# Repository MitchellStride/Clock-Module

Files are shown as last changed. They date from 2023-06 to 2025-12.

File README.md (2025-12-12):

# 🐦 Hummingbird RP2040 Clock Module ⏰

[]() 
[]() 

[]() 
[]() 

The **Hummingbird RP2040 Clock Module** is designed for crafting artisan clocks by pairing it with different clock faces. Its modular design allows this project to be shared across various display technologies.

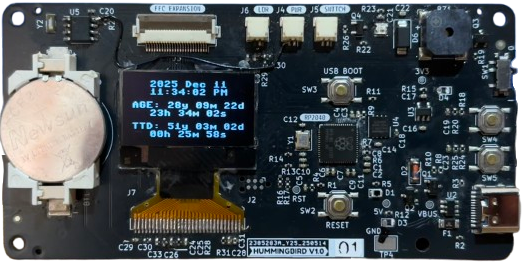
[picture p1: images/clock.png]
Clock Display


The test OLED above shows time, my age, and my time to death countdown based on my life expectancy.

---

## 🔧 Features
- Raspberry Pi RP2040 microcontroller with dual-core ARM Cortex-M0+
- Highly compatible with JLCPCB's basic SMT components and 2L stackup for cost
- Powered via USB-C with ESD and reverse polarity protection
- DS1307Z+ RTC with CR2032 coin cell backup
- Single-sided design for a compact, flush mount
- Photocell/LDR support for automatic display dimming
- Additional features: piezoelectric buzzer, RGB LED, power switch, and optional OLED
- FFC expansion for modular clock face integration

---

## 📦 Status
> The PCBA has arrived, and is working, it needed one bodge. FW is done.

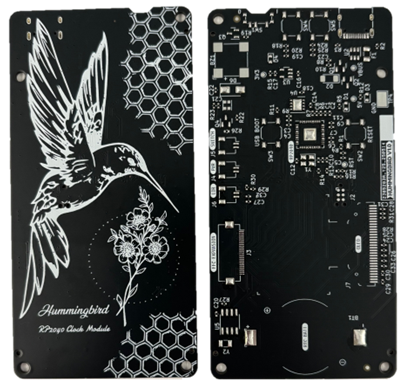
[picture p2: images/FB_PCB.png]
Front and back PCB


---

## 💡 Clock Ideas
Clocks I plan to build using this module:

<details>
<summary>Click to expand</summary>

- **Life Clock:** A countdown to estimated time of death using seven-segment displays
- **Nixie Clock:** A personal take on the classic Nixie tube clock, featuring IN-12 tubes
- **0402 Year Calendar** Inspired by the Yetch THE EVERY DAY GOAL CALENDAR

</details>

---

## 📝 Notes

<details>
<summary>Click to expand</summary>

- I had a few issues with the v1 hardware design since I completed it in roughly two days. Might do a v2.
- From 2024 (schematic design) to 2025 (layout), JLC PCB assembly changed many basic components and increased extended reel fees from $1 → $3, significantly affecting small-run costs.
- The cost per assembled PCB is approximately $8–10 USD, excluding setup fees. A total order of 2 PCBAs + 3 PCBs came to ~$57 + ~$17 shipping. After discounts, the total spent was ~$70 USD, plus $10–20 for extra parts from LCSC or Digikey. The largest expense was reel fees ($30).

See: -> ./images/cost2.png

</details>

---

## 🖼️ Image Appendix

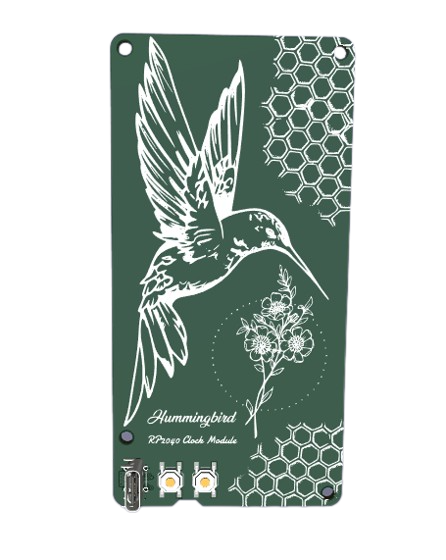
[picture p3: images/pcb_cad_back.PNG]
PCB Back


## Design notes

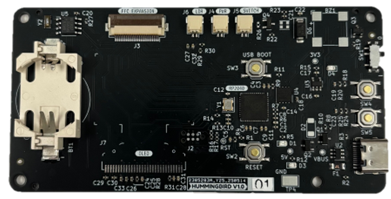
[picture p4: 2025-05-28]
images/F_PCBA1.png

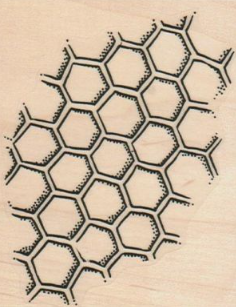
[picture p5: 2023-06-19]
images/assets/comb.PNG

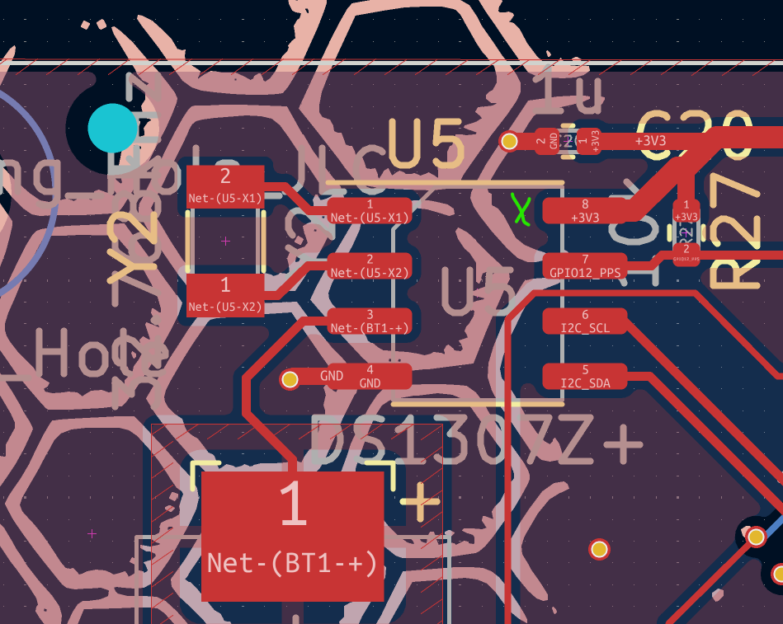
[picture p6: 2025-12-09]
images/ICs/rtc.png

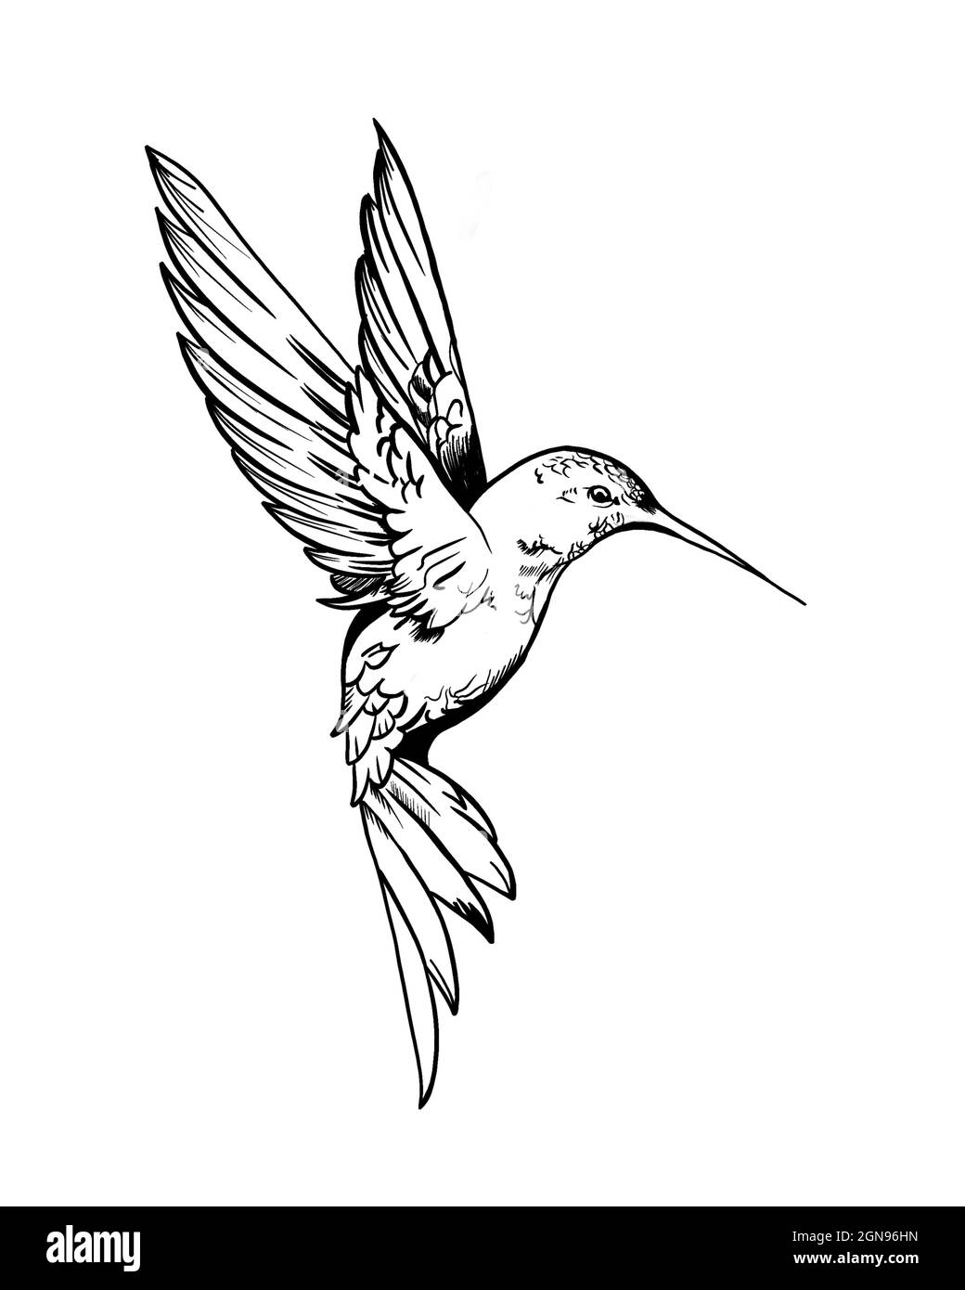
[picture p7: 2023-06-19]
images/assets/bird.jpg

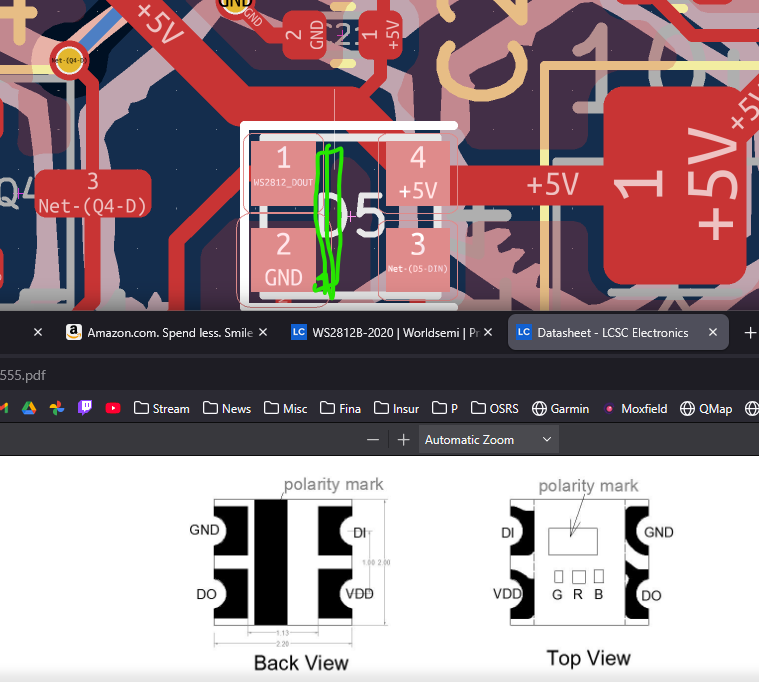
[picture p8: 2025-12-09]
images/ICs/rgb.png

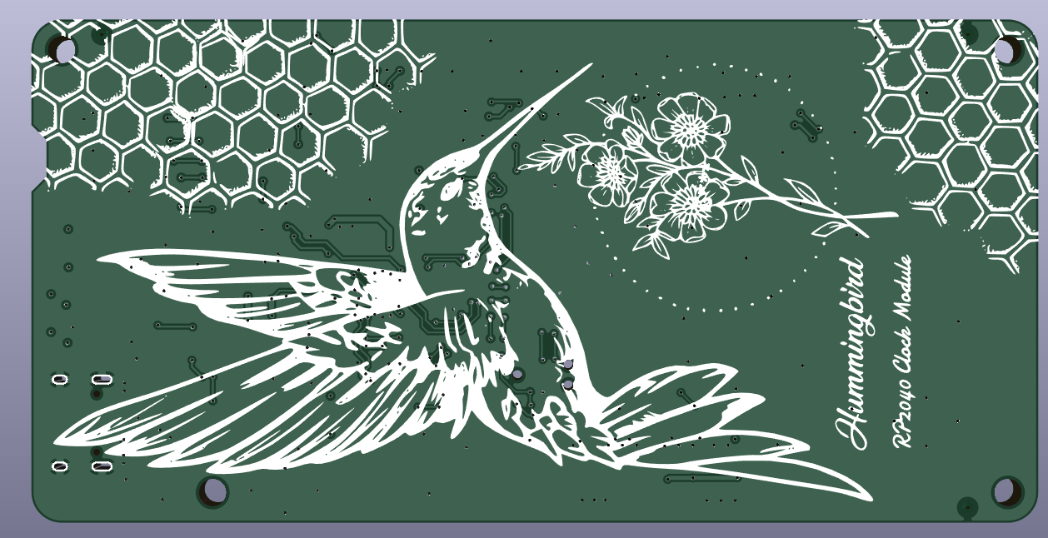
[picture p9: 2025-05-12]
images/20251205_bot3d.png

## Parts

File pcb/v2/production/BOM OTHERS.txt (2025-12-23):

Extras to Order not on PCB BOM:
- C5248005 FFC and assorted, reverse too
- C125626 GL5516 LDR
- OLED 
Wisevision N096-2864KSWEG01-H30
LCSC PN: C2890596
Controller  	SSD1306
- CR2032 Battery

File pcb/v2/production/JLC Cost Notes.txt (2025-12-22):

JLC Cost Notes

Cost https://jlcpcb.com/help/article/pcb-assembly-price
PCBA Type	Economic PCBA	Standard PCBA
Setup fee	$8		$25/Single-side
				$50/Double-side
Stencil also 	1.50 		vs 8
Feeders Fee	$3/ Extended	$1.5 basic/Extended

Economic Limits
Single sided placement (SMT/Thru-hole) 2,4,6-layers
Minimum Package 0402
Minimum IC Pin Spacing 0.4mm vs 0.35mm
Minimum BGA Spacing 0.5mm(center to center) vs 0.35mm(center to center)

SolderMask Colors https://jlcpcb.com/capabilities/pcb-assembly-capabilities
2L, All
4L, Green

2L, Any color, Single Side
4L, Green Single Sided, is a great value choice

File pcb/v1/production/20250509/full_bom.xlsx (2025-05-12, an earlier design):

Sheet: export
# | Reference | Qty | Value | Footprint | DNP | LCSC PN | digi
1 | BT1 | 1 | CR2032 | stride_footprints:Q&J_CR2032-BS-6-1 |  | C70377
2 | BZ1 | 1 | CMT-8504-100-SMT-TR | Buzzer_Beeper:MagneticBuzzer_CUI_CMT-8504-100-SMT |  |  | 102-CMT-8504-100-SMT-CT-ND
3 | C1, C22 | 2 | 10u | Capacitor_SMD:C_0402_1005Metric |  | C15525
4 | C2, C8, C18, C20, C21, C24, C26, C27, C29, C30, C33 | 11 | 1u | Capacitor_SMD:C_0402_1005Metric |  | C52923
5 | C3, C4, C5, C6, C7, C9, C10, C11, C14, C15, C19, C23, C25, C32 | 14 | 0.1u | Capacitor_SMD:C_0402_1005Metric |  | C1525
6 | C12, C13 | 2 | 10p | Capacitor_SMD:C_0402_1005Metric |  | C32949
7 | C16, C17, C31 | 3 | 4.7u | Capacitor_SMD:C_0402_1005Metric |  | C23733
8 | C28 | 1 | 2.2u | Capacitor_SMD:C_0402_1005Metric |  | C12530
9 | D1 | 1 | LED_Y | LED_SMD:LED_0603_1608Metric |  | C72038
10 | D2 | 1 | 5.6V | Diode_SMD:D_MiniMELF |  | C8062
11 | D3 | 1 | LED_B | LED_SMD:LED_0603_1608Metric |  | C72041
12 | D4 | 1 | LED_G | LED_SMD:LED_0603_1608Metric |  | C72043
13 | D5 | 1 | WS2812B-2020 | stride_footprints:WS2812B-2020 |  | C965555
14 | D6 | 1 | SS14 | Diode_SMD:D_SMA |  | C2480
15 | F1 | 1 | 12V 3A | Fuse:Fuse_1206_3216Metric |  | C516068
16 | J1 | 1 | USB_C_Receptacle_USB2.0 | ftp:USB-C-16p |  | C167321
17 | J3 | 1 | FFC 24 | Connector_FFC-FPC:Hirose_FH12-24S-0.5SH_1x24-1MP_P0.50mm_Horizontal |  | C202112
18 | J4, J5, J6 | 3 | 5V | Connector_JST:JST_SH_SM02B-SRSS-TB_1x02-1MP_P1.00mm_Horizontal |  | C160402
19 | J7 | 1 | OLED | stride_footprints:OLED-128O064D_edit_reverse_v2 |  | C2890596
20 | Q1, Q2 | 2 | AO3401A | Package_TO_SOT_SMD:SOT-23 |  | C15127
21 | Q3 | 1 | AO3400A | Package_TO_SOT_SMD:SOT-23 |  | C20917
22 | Q4 | 1 | 2N7002 | Package_TO_SOT_SMD:SOT-23 |  | C8545
23 | R1, R11, R18, R19, R24, R30 | 6 | 1k | Resistor_SMD:R_0402_1005Metric |  | C11702
24 | R2, R3 | 2 | 5.1k | Resistor_SMD:R_0402_1005Metric |  | C25905
25 | R4, R9, R20, R23, R25, R27, R28, R29 | 8 | 10k | Resistor_SMD:R_0402_1005Metric |  | C25744
26 | R5, R12 | 2 | 2.2k | Resistor_SMD:R_0402_1005Metric |  | C25879
27 | R6, R7 | 2 | 22 | Resistor_SMD:R_0402_1005Metric |  | C25092
28 | R8, R10 | 2 | 100k | Resistor_SMD:R_0402_1005Metric |  | C25741
29 | R13, R14 | 2 | 4.7k | Resistor_SMD:R_0402_1005Metric |  | C25900
30 | R15 | 1 | 300 | Resistor_SMD:R_0402_1005Metric |  | C25102
31 | R16, R17 | 2 | 0 | stride_footprints:R_0402_1005Metric_3pad |  | C17168
32 | R22 | 1 | 51 | Resistor_SMD:R_0402_1005Metric |  | C25125
33 | R26 | 1 | 10k | Resistor_SMD:R_0402_1005Metric | DNP | C25744
34 | R31 | 1 | 330k | Resistor_SMD:R_0402_1005Metric |  | C25778
35 | SW1 | 1 | SSSS811101 | stride_footprints:SSSS811101 |  | C109335
36 | SW2, SW3, SW4, SW5 | 4 | TS-1187A-B-A-B | stride_footprints:SW_SPST_TL3342_RT |  | C318884
37 | U1 | 1 | RP2040 | stride_footprints:QFN-56_EP_7x7_Pitch0.4mm |  | C2040
38 | U2 | 1 | SRV05-4 | Package_TO_SOT_SMD:SOT-23-6 |  | C85364
39 | U3 | 1 | RT9080-33GJ5 | Package_TO_SOT_SMD:SOT-23-5 |  | C841192
40 | U4 | 1 | W25Q64JV | Package_SON:WSON-8-1EP_4x4mm_P0.8mm_EP2.2x3mm |  | C2940195
41 | U5 | 1 | DS1307Z+ | Package_SO:SOIC-8_3.9x4.9mm_P1.27mm |  | C8959
42 | Y1 | 1 | XYDBPCNANF-12MHZ | Crystal:Crystal_SMD_3225-4Pin_3.2x2.5mm |  | C9002
43 | Y2 | 1 | 32.768kHz | Crystal:Crystal_SMD_3215-2Pin_3.2x1.5mm |  | C95361

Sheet: grouped by vendor
DIGIKEY
# | Reference | Qty | Value | Footprint | DNP | LCSC PN | digi
2 | BZ1 | 1 | CMT-8504-100-SMT-TR | Buzzer_Beeper:MagneticBuzzer_CUI_CMT-8504-100-SMT |  |  | 102-CMT-8504-100-SMT-CT-ND
 | JST SR/SZ/SH SERIES:
 | CRIMP | SSH-003T
 | HOUSING-2 | SHR-02V-S
 | CABLE-2 | 455-3619-ND
 | HOUSING-4 | SHR-04V-S
 | CABLE-4 | 455-3632-ND
 | LDR: 1528-2141-ND
OTHER
# | Reference | Qty | Value | Footprint | DNP | LCSC PN | digi | note
1 | BT1 | 1 | CR2032 | stride_footprints:Q&J_CR2032-BS-6-1 |  | C70377 |  | Need CR2032 Battery, try scrap mobos
LCSC
# | Reference | Qty | Value | Footprint | DNP | LCSC PN | digi | note
 | Hirose_FFC 24:
 | FFC SAME C36268
 | FFC OPP. C24318
10 | D2 | 1 | 5.6V | Diode_SMD:D_MiniMELF |  | C8062
JLC
# | Reference | Qty | Value | Footprint | DNP | LCSC PN | digi | note
3 | C1, C22 | 2 | 10u | Capacitor_SMD:C_0402_1005Metric |  | C15525
4 | C2, C8, C18, C20, C21, C24, C26, C27, C29, C30, C33 | 11 | 1u | Capacitor_SMD:C_0402_1005Metric |  | C52923
5 | C3, C4, C5, C6, C7, C9, C10, C11, C14, C15, C19, C23, C25, C32 | 14 | 0.1u | Capacitor_SMD:C_0402_1005Metric |  | C1525
6 | C12, C13 | 2 | 10p | Capacitor_SMD:C_0402_1005Metric |  | C32949
7 | C16, C17, C31 | 3 | 4.7u | Capacitor_SMD:C_0402_1005Metric |  | C23733
8 | C28 | 1 | 2.2u | Capacitor_SMD:C_0402_1005Metric |  | C12530
9 | D1 | 1 | LED_Y | LED_SMD:LED_0603_1608Metric |  | C72038
11 | D3 | 1 | LED_B | LED_SMD:LED_0603_1608Metric |  | C72041
12 | D4 | 1 | LED_G | LED_SMD:LED_0603_1608Metric |  | C72043
10 | D2 | 1 | 5.6V | Diode_SMD:D_MiniMELF |  | C8062
13 | D5 | 1 | WS2812B-2020 | stride_footprints:WS2812B-2020 |  | C965555
14 | D6 | 1 | SS14 | Diode_SMD:D_SMA |  | C2480
15 | F1 | 1 | 12V 3A | Fuse:Fuse_1206_3216Metric |  | C516068
16 | J1 | 1 | USB_C_Receptacle_USB2.0 | ftp:USB-C-16p |  | C167321
17 | J3 | 1 | FFC 24 | Connector_FFC-FPC:Hirose_FH12-24S-0.5SH_1x24-1MP_P0.50mm_Horizontal |  | C202112
18 | J4, J5, J6 | 3 | 5V | Connector_JST:JST_SH_SM02B-SRSS-TB_1x02-1MP_P1.00mm_Horizontal |  | C160402
19 | J7 | 1 | OLED | stride_footprints:OLED-128O064D_edit_reverse_v2 |  | C2890596
20 | Q1, Q2 | 2 | AO3401A | Package_TO_SOT_SMD:SOT-23 |  | C15127
21 | Q3 | 1 | AO3400A | Package_TO_SOT_SMD:SOT-23 |  | C20917
22 | Q4 | 1 | 2N7002 | Package_TO_SOT_SMD:SOT-23 |  | C8545
23 | R1, R11, R18, R19, R24, R30 | 6 | 1k | Resistor_SMD:R_0402_1005Metric |  | C11702
24 | R2, R3 | 2 | 5.1k | Resistor_SMD:R_0402_1005Metric |  | C25905
25 | R4, R9, R20, R23, R25, R27, R28, R29 | 8 | 10k | Resistor_SMD:R_0402_1005Metric |  | C25744
26 | R5, R12 | 2 | 2.2k | Resistor_SMD:R_0402_1005Metric |  | C25879
27 | R6, R7 | 2 | 22 | Resistor_SMD:R_0402_1005Metric |  | C25092
28 | R8, R10 | 2 | 100k | Resistor_SMD:R_0402_1005Metric |  | C25741
29 | R13, R14 | 2 | 4.7k | Resistor_SMD:R_0402_1005Metric |  | C25900
30 | R15 | 1 | 300 | Resistor_SMD:R_0402_1005Metric |  | C25102
31 | R16, R17 | 2 | 0 | stride_footprints:R_0402_1005Metric_3pad |  | C17168
32 | R22 | 1 | 51 | Resistor_SMD:R_0402_1005Metric |  | C25125
33 | R26 | 1 | 10k | Resistor_SMD:R_0402_1005Metric | DNP | C25744
34 | R31 | 1 | 330k | Resistor_SMD:R_0402_1005Metric |  | C25778
35 | SW1 | 1 | SSSS811101 | stride_footprints:SSSS811101 |  | C109335
36 | SW2, SW3, SW4, SW5 | 4 | TS-1187A-B-A-B | stride_footprints:SW_SPST_TL3342_RT |  | C318884
37 | U1 | 1 | RP2040 | stride_footprints:QFN-56_EP_7x7_Pitch0.4mm |  | C2040
38 | U2 | 1 | SRV05-4 | Package_TO_SOT_SMD:SOT-23-6 |  | C85364
39 | U3 | 1 | RT9080-33GJ5 | Package_TO_SOT_SMD:SOT-23-5 |  | C841192
40 | U4 | 1 | W25Q64JV | Package_SON:WSON-8-1EP_4x4mm_P0.8mm_EP2.2x3mm |  | C2940195
41 | U5 | 1 | DS1307Z+ | Package_SO:SOIC-8_3.9x4.9mm_P1.27mm |  | C8959
42 | Y1 | 1 | XYDBPCNANF-12MHZ | Crystal:Crystal_SMD_3225-4Pin_3.2x2.5mm |  | C9002
43 | Y2 | 1 | 32.768kHz | Crystal:Crystal_SMD_3215-2Pin_3.2x1.5mm |  | C95361

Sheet: jlc csv
Designator | Footprint | Quantity | Value | LCSC Part #
BT1 | Q&J_CR2032-BS-6-1 | 1 | CR2032 | C70377
C1, C22 | 402 | 2 | 10u | C15525
C10, C11, C14, C15, C19, C23, C25, C3, C32, C4, C5, C6, C7, C9 | 402 | 14 | 0.1u | C1525
C12, C13 | 402 | 2 | 10p | C32949
C16, C17, C31 | 402 | 3 | 4.7u | C23733
C18, C2, C20, C21, C24, C26, C27, C29, C30, C33, C8 | 402 | 11 | 1u | C52923
C28 | 402 | 1 | 2.2u | C12530
D1 | 603 | 1 | LED_Y | C2296
D3, D4 | 805 | 2 | LED_G | C2297
D2 | D_MiniMELF | 1 | 5.6V | C8062
D5 | WS2812B-2020 | 1 | WS2812B-2020 | C965555
D6 | D_SMA | 1 | SS14 | C2480
F1 | 1206 | 1 | 12V 3A | C516068
J1 | USB-C-16p | 1 | USB_C_Receptacle_USB2.0 | C167321
J3 | Hirose_FH12-24S-0.5SH_1x24-1MP_P0.50mm_Horizontal | 1 | FFC 24 | C202112
J4, J5, J6 | JST_SH_SM02B-SRSS-TB_1x02-1MP_P1.00mm_Horizontal | 3 | 5V | C160402
Q1, Q2 | SOT-23 | 2 | AO3401A | C15127
Q3 | SOT-23 | 1 | AO3400A | C20917
Q4 | SOT-23 | 1 | 2N7002 | C8545
R1, R11, R18, R19, R24, R30 | 402 | 6 | 1k | C11702
R10, R8 | 402 | 2 | 100k | C25741
R12, R5 | 402 | 2 | 2.2k | C25879
R13, R14, R21 | 402 | 2 | 4.7k | C25900
R15 | 402 | 1 | 300 | C25102
R16, R17 | 402 | 2 | 0 | C17168
R2, R3 | 402 | 2 | 5.1k | C25905
R20, R23, R25, R26, R27, R28, R29, R4, R9 | 402 | 9 | 10k | C25744
R22 | 402 | 1 | 51 | C25125
R31 | 402 | 1 | 330k | C25778
R6, R7 | 402 | 2 | 22 | C25092
SW1 | SSSS811101 | 1 | SSSS811101 | C109335
SW2, SW3, SW4, SW5 | SW_SPST_TL3342_RT | 4 | TS-1187A-B-A-B | C318884
U1 | QFN-56_EP_7x7_Pitch0.4mm | 1 | RP2040 | C2040
U2 | SOT-23-6 | 1 | SRV05-4 | C85364
U3 | SOT-23-5 | 1 | RT9080-33GJ5 | C841192
U4 | WSON-8-1EP_4x4mm_P0.8mm_EP2.2x3mm | 1 | W25Q64JV | C2940195
U5 | SOIC-8_3.9x4.9mm_P1.27mm | 1 | DS1307Z+ | C8959
Y1 | Crystal_SMD_3225-4Pin_3.2x2.5mm | 1 | XYDBPCNANF-12MHZ | C9002
Y2 | Crystal_SMD_3215-2Pin_3.2x1.5mm | 1 | 32.768kHz | C95361

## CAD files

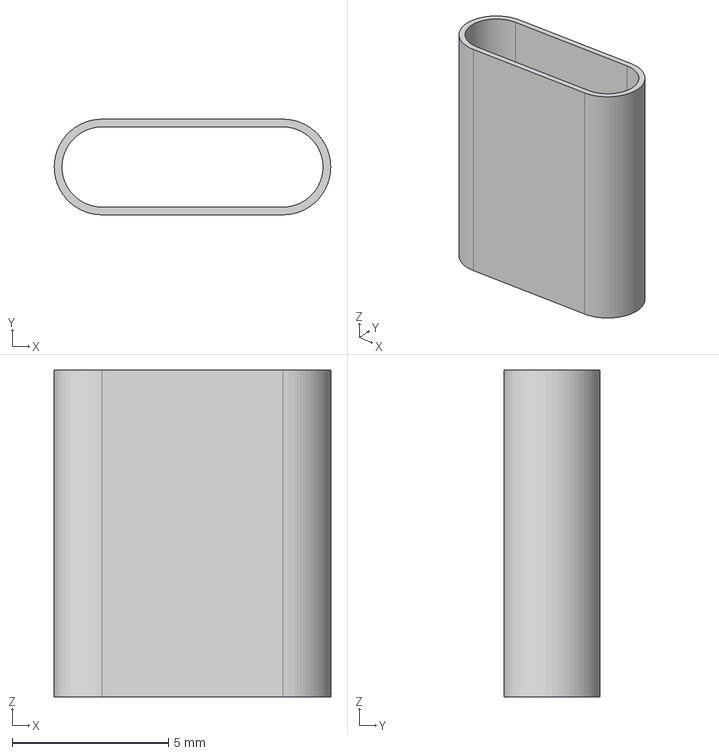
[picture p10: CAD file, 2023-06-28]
mechanical/models/USBCv2.step
8.84 x 3.06 x 10.4 mm

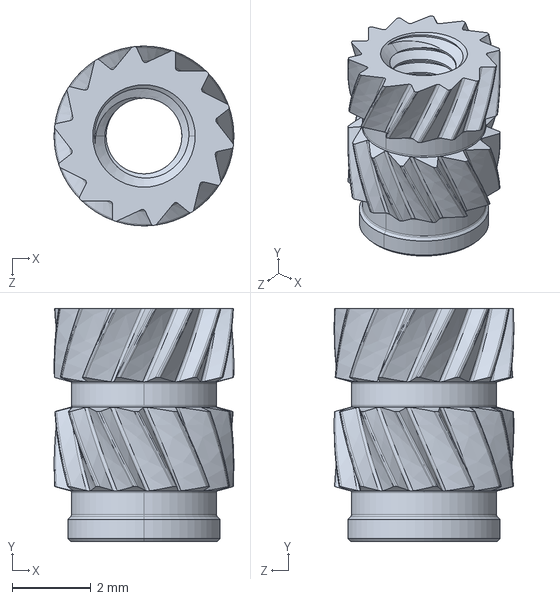
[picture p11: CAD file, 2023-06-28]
clock_pcb/mechanical/models/94459A439_Heat-Set Inserts for Plastic.STEP
4.55 x 5.90 x 4.55 mm

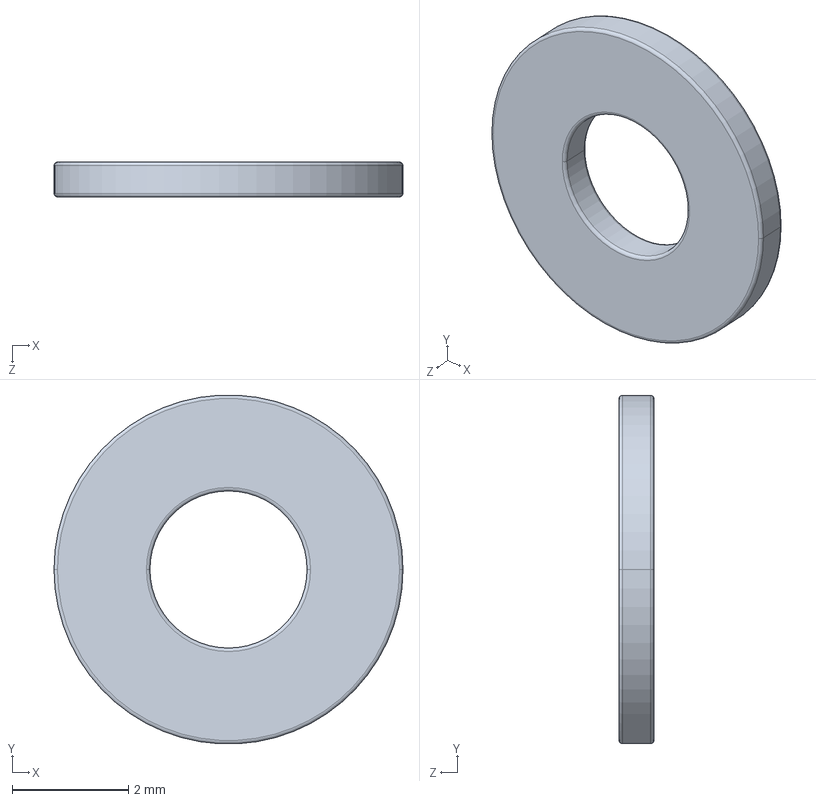
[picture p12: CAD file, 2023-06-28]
clock_pcb/mechanical/models/91635A180_Brass Washer.STEP
6.00 x 5.99 x 0.6 mm

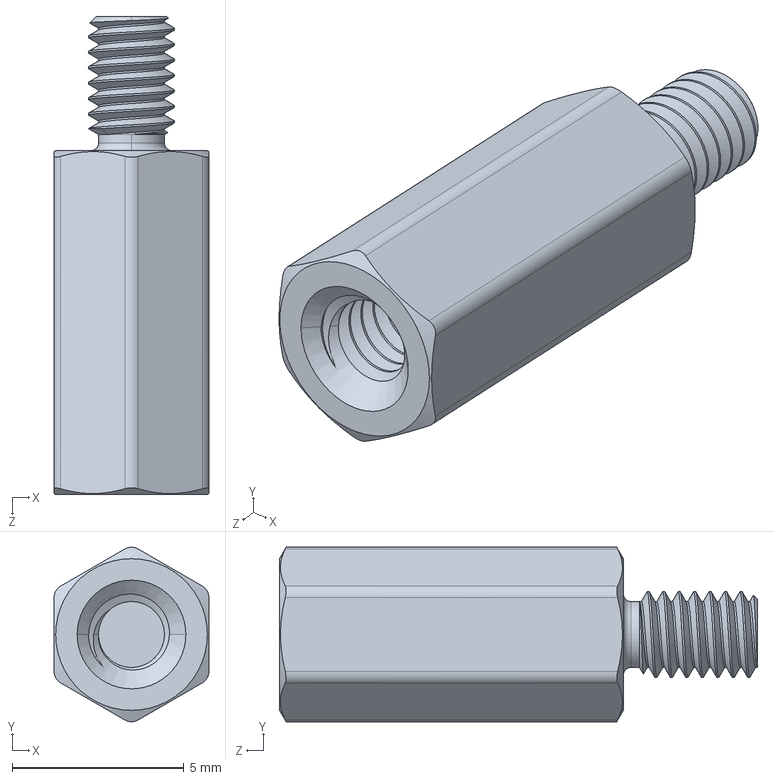
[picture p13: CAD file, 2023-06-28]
clock_pcb/mechanical/models/93655A008_Male-Female Threaded Hex Standoff.STEP
4.50 x 5.08 x 13.9 mm

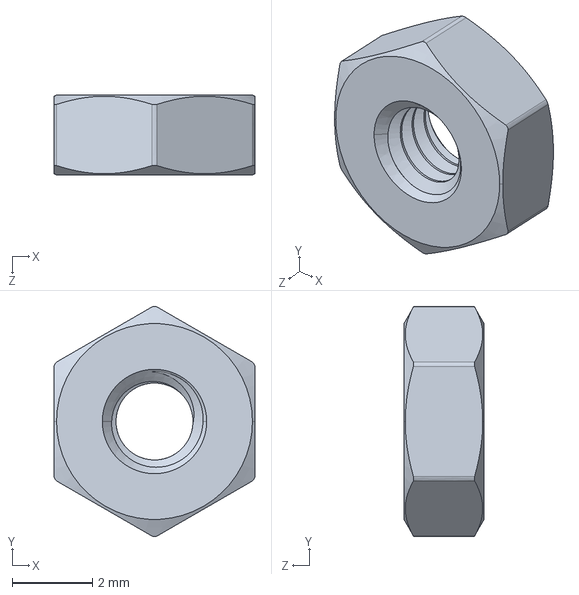
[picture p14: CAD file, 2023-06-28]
clock_pcb/mechanical/models/90690A035_Brass Hex Nut.STEP
5.00 x 5.72 x 2.00 mm

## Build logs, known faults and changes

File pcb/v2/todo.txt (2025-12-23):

#To Do V2
re-add all footprints
Look at rules setup really good again Board and net classes
	online JLC rules txt
Check impedance 7268 glass stackup? 
add net class to power in sch
Silk on WS2812
Move OLED to seperate PCB, Just asm FFC and caps and solder pads
	using same side FFC I need to invert the pins, so flip conn pin 1
	add second ffc conn to this pcb.

Gerber Review
Verify holes on SSSS811101

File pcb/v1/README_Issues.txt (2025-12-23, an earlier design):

# V1
## Issues
* Holes disappeared from SSS slide pwr switch footprint for some reason
* Silk On(|) and Off(O) are backwards
* Buttons not actually connected to pins
* SW1 stopped working on one unit for 5mins, then started working again. Power wouldnt turn off.
* R28 silk in wrong spot
* DS1307Z+ needs 5v not 3.3V oof, need to desolder, remove pin, flush cut or tape, then wire over 5v0, i2c Vih is fine at 3v3
* D1 D4 too bright
* Soldering an OLED sucks, should use FFC Connector in the future
* Needs a schematic note that ext switch only works when PCB switch if off or not GND, this could be better
* Ext conns like the LDR should have a second fuse just in case
* Silk on WS2812B-2020 got cut in fab for some reason, never got to test this part, fet may be to slow after simulation.
* Add extended property or basic to BOM jlc_status
* Adjust silk on CR2032 holder +/- 
* put rtc address on schematic 110 1000 R/W 0x68
* Make oled addr 0x3C clearer 011 1100 R/W 0x3C
* RTC built was DS1302 not DS1307Z , select a cheap non 5V part

## Add
* Red PBAD LED
* LDR THT Holes
* different logic level shifter and RGBW LED?

Extended Parts
Fix these
U2 SRV05-4-P-T7 ESD Diode, bom = 0 this one
R31 20 ohms?
Select new 0603 leds that are basic, run them off 5v for good green

Unselected Parts because I had them?
D2 Zener and D5 WS2812B-2020

Consider
SW1 SSSS811101
U3 RT9080-33GJ5
DS1307 RTC and Y2 and CR2032 holder
J4 5 6, SM02B-SRSS-TB(LF)(SN)

Need
USBC
RP2040
J3 FFC and 1.25 expensive 

#V2 notes
look at impedance control for free?
Make mtg holes plated?
Make 

Gerber Review
Verify holes on SSSS811101
Silk on

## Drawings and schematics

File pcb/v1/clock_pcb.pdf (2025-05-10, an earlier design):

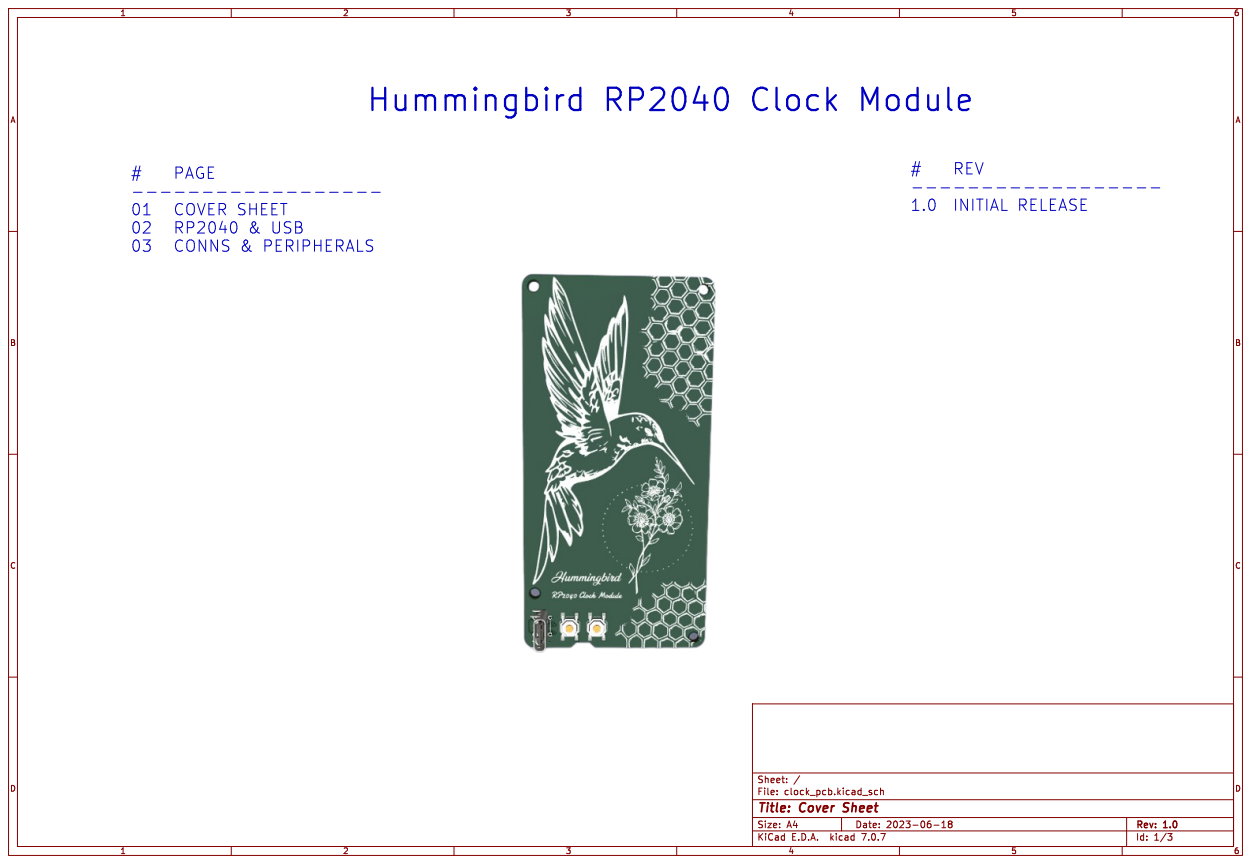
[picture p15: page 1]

Id: 1/3 Title: Cover Sheet File: clock_pcb.kicad_sch Sheet: /

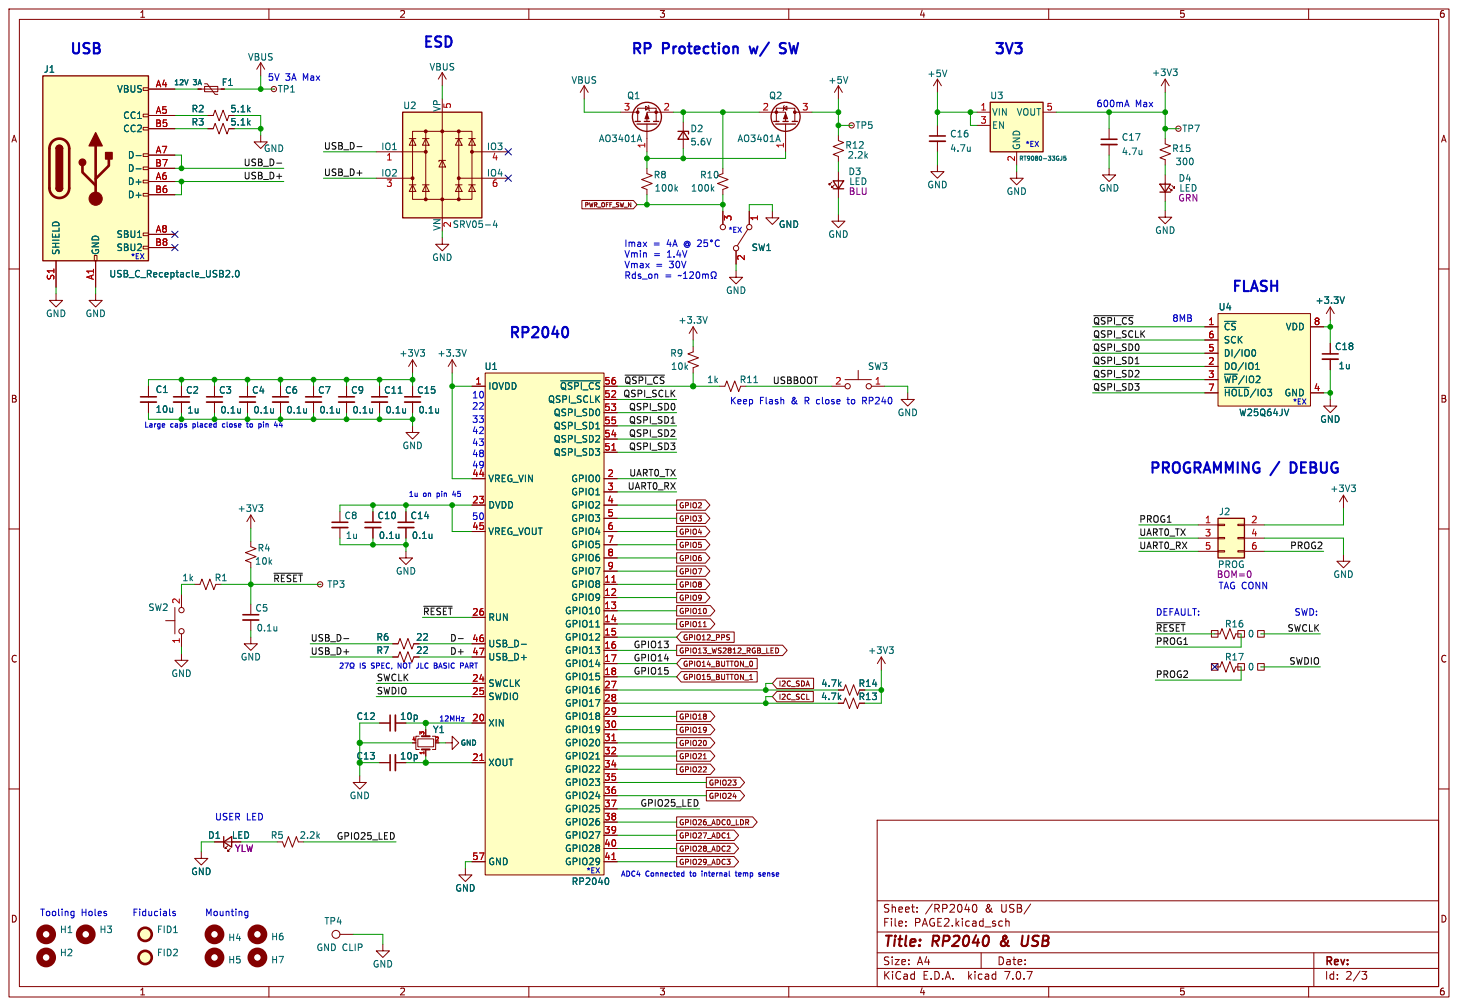
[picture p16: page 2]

Keep Flash & R close to RP240

þÿ27©IS SPEC, NOT JLC BASIC PART 49

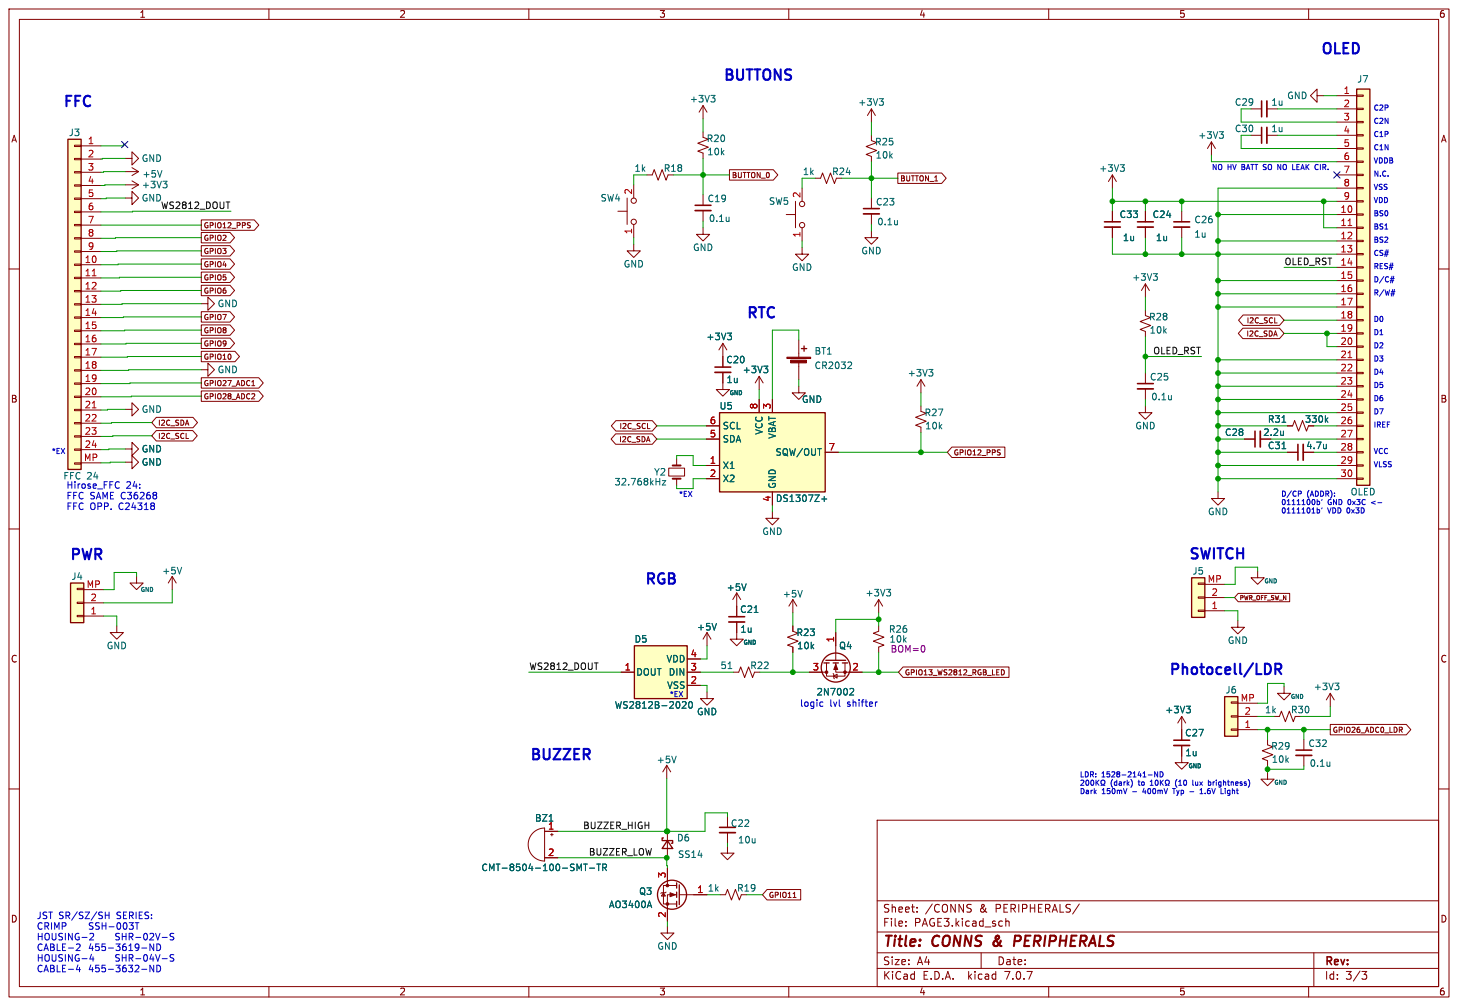
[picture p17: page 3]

4 SDA 5 SCL 6 SQW/OUT 7 VCC

Hirose_FFC 24: FFC SAME C36268 FFC OPP. C24318
*EX PWR

2 3 D5 WS2812B-2020 DOUT 1 VSS 2 DIN 3 VDD 4GND

Id: 3/3 Title: CONNS & PERIPHERALS

HOUSING-4 SHR-04V-S CABLE-4 455-3632-ND

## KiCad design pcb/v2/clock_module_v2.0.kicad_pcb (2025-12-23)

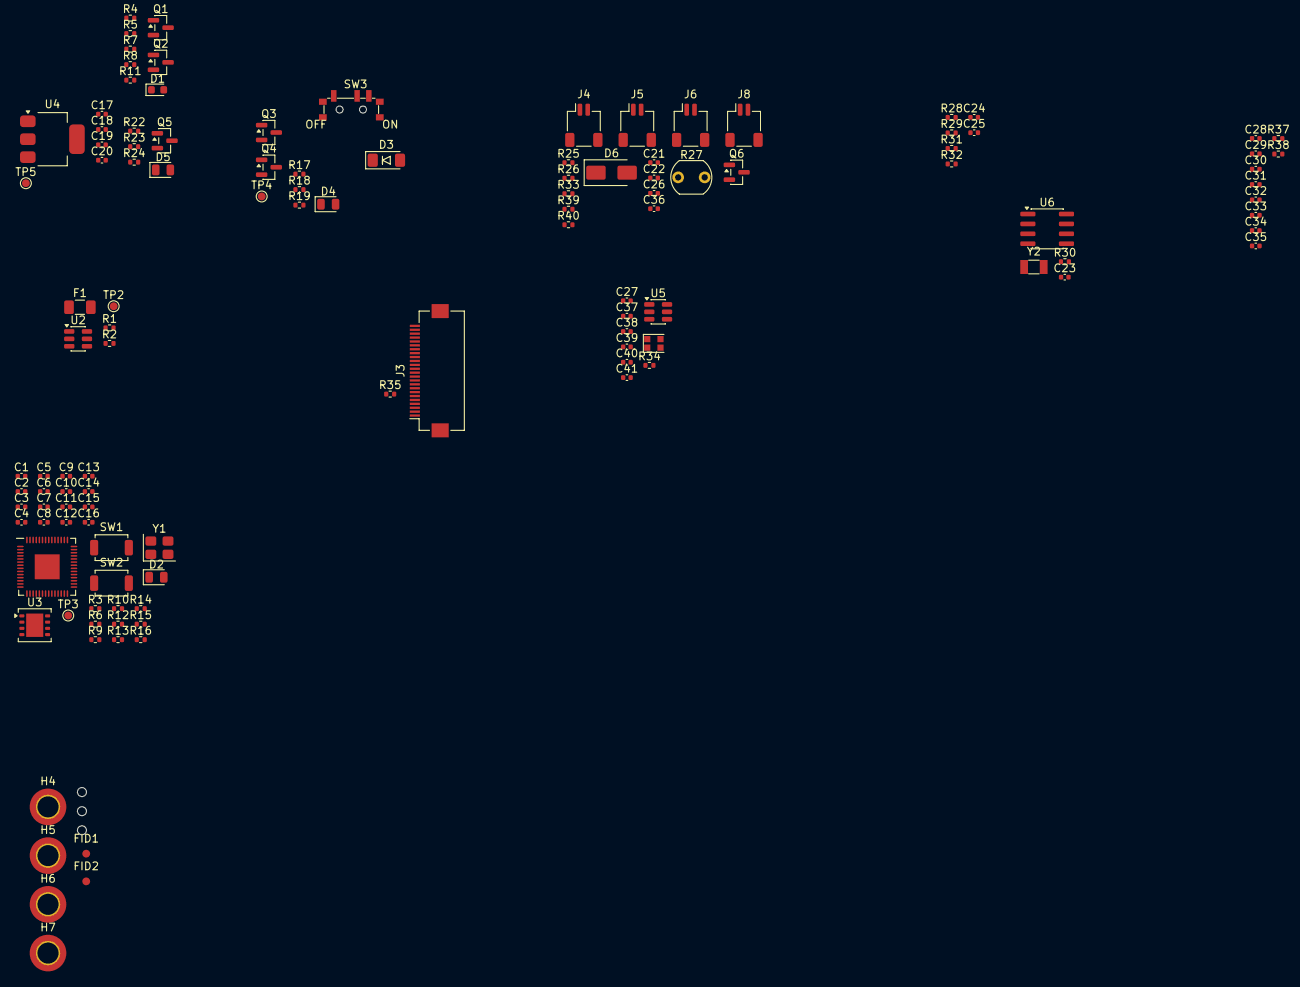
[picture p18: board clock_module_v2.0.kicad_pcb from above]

Board: 4 copper layers, 121 parts (0 on the bottom side), 65 nets, no tracks yet.

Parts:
C1, C19, C26: 10u; C_0402_1005Metric
C2, C8, C16, C21, C23, C27, C28, C29, C31, C33, C34, C37, C38, C39, C40, C41: 1u; C_0402_1005Metric
C3, C4, C5, C6, C7, C9, C10, C11, C14, C15, C22, C24, C25, C30, C36: 0.1u; C_0402_1005Metric
C12, C13: 10p; C_0402_1005Metric
C17, C18, C20, C35: 4.7u; C_0402_1005Metric
C32: 2.2u; C_0402_1005Metric
D1: Red; LED_0603_1608Metric
D2: YLW; LED_0805_2012Metric
D3: 5.6V; D_MiniMELF
D4, D5: GRN; LED_0805_2012Metric
D6: SS14; D_SMA
D7: WS2812B-2020
F1: 12V 3A; Fuse_1206_3216Metric
FID1, FID2: Fiducial; Fiducial_1mm_Mask2mm
H1, H2, H3: Tooling_Hole_JLC; ToolingHole_1.152mm
H4, H5, H6, H7: Mounting_Hole; MountingHole_2.7mm_M2.5_DIN965_Pad_TopBottom
J3: FFC 24; Hirose_FH12-24S-0.5SH_1x24-1MP_P0.50mm_Horizontal
J4: PWR; JST_SH_SM02B-SRSS-TB_1x02-1MP_P1.00mm_Horizontal
J5: SW; JST_SH_SM02B-SRSS-TB_1x02-1MP_P1.00mm_Horizontal
J6, J8: LDR; JST_SH_SM02B-SRSS-TB_1x02-1MP_P1.00mm_Horizontal
Q1, Q2, Q5, Q6: AO3400A; SOT-23
Q3, Q4: AO3401A; SOT-23
R1, R2: 5.1k; R_0402_1005Metric
R3, R4, R13, R22, R26, R28, R31, R33, R40: 1k; R_0402_1005Metric
R5, R8, R17, R18, R23: 100k; R_0402_1005Metric
R6, R12, R25, R29, R30, R32, R37, R39: 10k; R_0402_1005Metric
R7, R11, R14, R19, R24: 2.2k; R_0402_1005Metric
R9, R10: 22; R_0402_1005Metric
R15, R16: 4.7k; R_0402_1005Metric
R27: GL5516; R_LDR_5.1x4.3mm_P3.4mm_Vertical
R34: 49.9; R_0402_1005Metric
R35: 0; R_0402_1005Metric
R38: 330k; R_0402_1005Metric
SW1, SW2: TS-1187A-B-A-B; SW_SPST_TS-1088-xR020
SW3: SSSS811101
TP2: VBUS; TestPoint_Pad_D1.0mm
TP3: RST; TestPoint_Pad_D1.0mm
TP4: 5V; TestPoint_Pad_D1.0mm
TP5: 3V3; TestPoint_Pad_D1.0mm
U1: RP2040; QFN-56_EP_7x7_Pitch0.4mm
U2: SRV05-4; SOT-23-6
U3: W25Q64JV; WSON-8-1EP_4x4mm_P0.8mm_EP2.2x3mm
U4: AMS1117-3.3; SOT-223-3_TabPin2
U5: SN74LVC1T45DBV; SOT-23-6
U6: DS1307Z+; SOIC-8_3.9x4.9mm_P1.27mm
Y1: XYDBPCNANF-12MHZ; Crystal_SMD_3225-4Pin_3.2x2.5mm
Y2: 32.768kHz; Crystal_SMD_3215-2Pin_3.2x1.5mm

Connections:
+3.3V: C16.1, R12.1, U1.1 (IOVDD), U1.10 (IOVDD), U1.22 (IOVDD), U1.33 (IOVDD), U1.42 (IOVDD), U1.43 (ADC_AVDD), U1.44 (VREG_VIN), U1.48 (USB_VDD), U1.49 (IOVDD), U3.8 (VDD)
+3V3: C1.1, C2.1, C3.1, C4.1, C6.1, C7.1, C9.1, C11.1, C15.1, C19.1, C20.1, C21.1, C28.1, C29.1, C31.1, C38.1, J3.4, R4.1, R6.1, R15.2, R16.2, R22.1, R26.2, R29.1, R30.1, R32.1, R37.1, R40.2, TP5.1, U4.2 (VO), U5.6 (VCCB)
+5V: C17.1, C18.1, C23.1, C26.1, C27.1, C37.1, C39.1, C40.1, C41.1, D6.1 (K), D7.4 (VDD), J3.3, J8.2, Q4.3 (D), R19.2, TP4.1, U4.3 (VI), U5.1 (VCCA), U6.8 (VCC)
/02 RP2040 & USB/D+: R10.2, U1.47 (USB_D+)
/02 RP2040 & USB/D-: R9.2, U1.46 (USB_D-)
/02 RP2040 & USB/GPIO25_LED: R14.2, U1.37 (GPIO25)
/02 RP2040 & USB/QSPI_SCLK: U1.52 (QSPI_SCLK), U3.6 (SCK)
/02 RP2040 & USB/QSPI_SD0: U1.53 (QSPI_SD0), U3.5 (DI/IO0)
/02 RP2040 & USB/QSPI_SD1: U1.55 (QSPI_SD1), U3.2 (DO/IO1)
/02 RP2040 & USB/QSPI_SD2: U1.54 (QSPI_SD2), U3.3 (~WP/IO2)
/02 RP2040 & USB/QSPI_SD3: U1.51 (QSPI_SD3), U3.7 (~HOLD/IO3)
/02 RP2040 & USB/USBBOOT: R13.2, SW2.2
/02 RP2040 & USB/USB_D+: R10.1, U2.3 (IO2)
/02 RP2040 & USB/USB_D-: R9.1, U2.1 (IO1)
/02 RP2040 & USB/~QSPI_CS: R12.2, R13.1, U1.56 (~QSPI_CS), U3.1 (~CS)
/02 RP2040 & USB/~RESET: C5.1, R3.2, R6.2, TP3.1, U1.26 (RUN)
/03 CONNS & PERIPHERALS/BUZZER_LOW: D6.2 (A), J8.1, Q6.3 (D)
/03 CONNS & PERIPHERALS/OLED_RST: C30.1, R37.2
GND: C1.2, C2.2, C3.2, C4.2, C5.2, C6.2, C7.2, C8.2, C9.2, C10.2, C11.2, C12.1, C13.1, C14.2, C15.2, C16.2, C17.2, C18.2, C19.2, C20.2, C21.2, C22.2, C23.2, C24.2, C25.2, C26.2, C27.2, C28.2, C29.2, C30.2, C31.2, C32.1, C35.1, C36.2, C37.2, C38.2, C39.2, C40.2, C41.2, D2.1 (K), D4.1 (K), D7.2 (VSS), J3.2, J3.5, J3.13, J3.18, J3.21, J3.24, J3.MP (MountingPoint), J4.1, J4.MP (Mounting_Point), J5.1, J5.MP (Mounting_Point), J6.MP (Mounting_Point), J8.MP (Mounting_Point), Q1.2 (S), Q2.2 (S), Q5.2 (S), Q6.2 (S), R1.2, R2.2, R5.2, R8.2, R23.2, R25.2, R38.1, R39.2, SW1.2, SW2.1, SW3.1 (A), SW3.2 (B), U1.19 (TESTEN), U1.57 (GND), U2.2 (VN), U3.4 (GND), U3.9 (GND), U4.1 (GND), U5.2 (GND), U5.5 (DIR), U6.4 (GND), Y1.2, Y1.4
GPIO2: J3.8, U1.4 (GPIO2)
GPIO3: J3.9, U1.5 (GPIO3)
GPIO4: J3.10, U1.6 (GPIO4)
GPIO5: J3.11, U1.7 (GPIO5)
GPIO6: J3.12, U1.8 (GPIO6)
GPIO7: J3.14, U1.9 (GPIO7)
GPIO8: J3.15, U1.11 (GPIO8)
GPIO9: J3.16, U1.12 (GPIO9)
GPIO10: J3.17, U1.13 (GPIO10)
GPIO11: R33.2, U1.14 (GPIO11)
GPIO12_PPS: R30.2, U1.15 (GPIO12), U6.7 (SQW/OUT)
GPIO13_WS2812_RGB_LED: U1.16 (GPIO13), U5.4 (B)
GPIO14_BUTTON_0: C24.1, R28.2, R29.2, U1.17 (GPIO14)
GPIO15_BUTTON_1: C25.1, R31.2, R32.2, U1.18 (GPIO15)
GPIO18: J3.19, U1.29 (GPIO18)
GPIO26_ADC0_LDR_EXT: C22.1, J6.1, R25.1, U1.38 (GPIO26)
GPIO27_ADC1_LDR: C36.1, R27.2, R39.1, U1.39 (GPIO27)
GPIO28_ADC2: J3.20, U1.40 (GPIO28)
I2C_SCL: J3.23, R15.1, U1.28 (GPIO17), U6.6 (SCL)
I2C_SDA: J3.22, R16.1, U1.27 (GPIO16), U6.5 (SDA)
unnamed: D1.2 (A), R11.1
unnamed: D1.1 (K), Q2.3 (D)
unnamed: D2.2 (A), R14.1
unnamed: D3.2 (A), Q3.1 (G), Q4.1 (G), R17.1
unnamed: D3.1 (K), Q3.2 (S), Q4.2 (S), R18.1
unnamed: D4.2 (A), R19.1
unnamed: D5.2 (A), R24.1
unnamed: D5.1 (K), Q5.3 (D)
unnamed: D7.3 (DIN), R34.1
unnamed: J3.7, R35.1
unnamed: J6.2, R26.1
unnamed: Q1.3 (D), Q2.1 (G), R7.1, R8.1
unnamed: Q1.1 (G), R4.2, R5.1
unnamed: Q5.1 (G), R22.2, R23.1
unnamed: Q6.1 (G), R33.1
unnamed: R3.1, SW1.1
unnamed: R27.1, R40.1
unnamed: C8.1, C10.1, C14.1, U1.23 (DVDD), U1.45 (VREG_VOUT), U1.50 (DVDD)
unnamed: C12.2, U1.20 (XIN), Y1.3
unnamed: C13.2, U1.21 (XOUT), Y1.1
unnamed: R34.2, U5.3 (A)
unnamed: U6.1 (X1), Y2.2
unnamed: U6.2 (X2), Y2.1
PWR_OFF_SW_N: J5.2, R17.2, R18.2, SW3.3 (C)
UNFUSED_VBUS: F1.2, J4.2
VBUS: F1.1, Q3.3 (D), R7.2, R11.2, R24.2, TP2.1, U2.5 (VP)

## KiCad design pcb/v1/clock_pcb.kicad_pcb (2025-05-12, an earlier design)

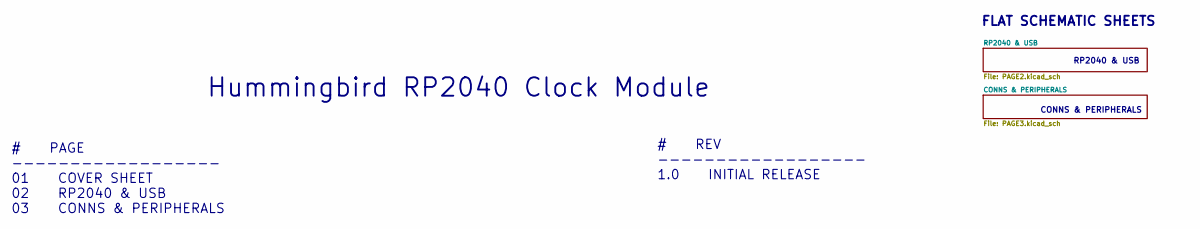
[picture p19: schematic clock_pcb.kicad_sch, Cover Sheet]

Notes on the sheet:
RP2040 & USB
CONNS & PERIPHERALS
Hummingbird RP2040 Clock Module
FLAT SCHEMATIC SHEETS
# REV ------------------ 1.0 INITIAL RELEASE
# PAGE ------------------ 01 COVER SHEET 02 RP2040 & USB 03 CONNS & PERIPHERALS

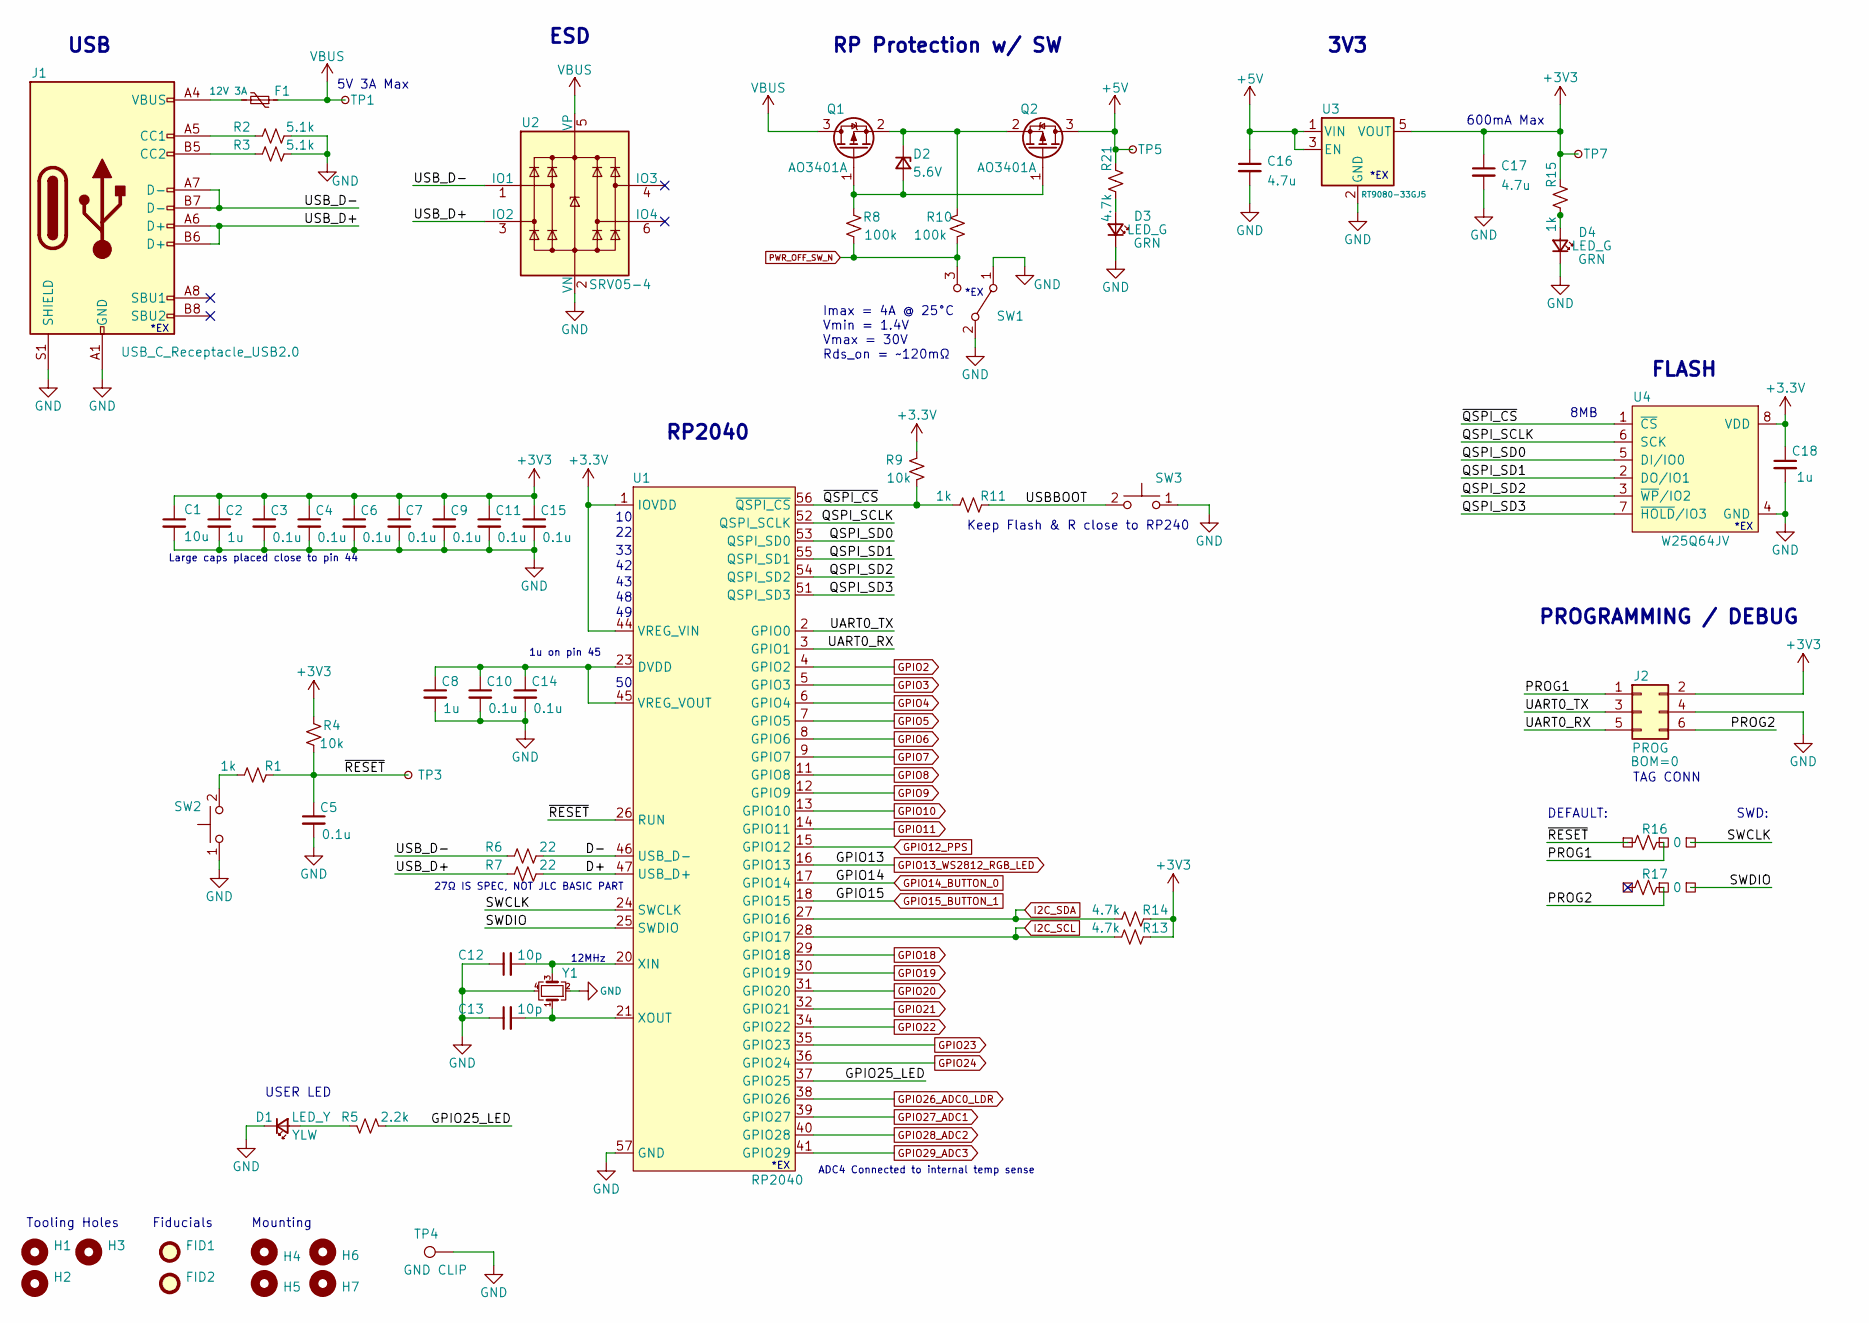
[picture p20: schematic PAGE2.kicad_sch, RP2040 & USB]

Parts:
C1: 10u; C_0402_1005Metric; LCSC PN C15525
C2, C8, C18: 1u; C_0402_1005Metric; LCSC PN C52923
C3, C4, C5, C6, C7, C9, C10, C11, C14, C15: 0.1u; C_0402_1005Metric; LCSC PN C1525
C12, C13: 10p; C_0402_1005Metric; LCSC PN C32949
C16, C17: 4.7u; C_0402_1005Metric; LCSC PN C23733
D1: LED_Y; LED_0805_2012Metric; LCSC PN C2296
D2: 5.6V; D_MiniMELF; LCSC PN C8062
D3, D4: LED_G; LED_0805_2012Metric; LCSC PN C2297
F1: 12V 3A; Fuse_1206_3216Metric; LCSC PN C516068
FID1, FID2: Fiducial; Fiducial_1mm_Mask2mm
H1, H2, H3: Tooling_Hole_JLC; JLC_Tooling_Hole
H4, H5, H6, H7: Mounting_Hole; MountingHole_2.7mm_M2.5
J1: USB_C_Receptacle_USB2.0; USB-C-16p; LCSC PN C167321
J2: PROG; Tag-Connect_TC2030-IDC-NL_2x03_P1.27mm_Vertical
Q1, Q2: AO3401A; SOT-23; LCSC PN C15127
R1, R11, R15: 1k; R_0402_1005Metric; LCSC PN C11702
R2, R3: 5.1k; R_0402_1005Metric; LCSC PN C25905
R4, R9: 10k; R_0402_1005Metric; LCSC PN C25744
R5: 2.2k; R_0402_1005Metric; LCSC PN C25879
R6, R7: 22; R_0402_1005Metric; LCSC PN C25092
R8, R10: 100k; R_0402_1005Metric; LCSC PN C25741
R13, R14, R21: 4.7k; R_0402_1005Metric; LCSC PN C25900
R16, R17: 0; R_0402_1005Metric_3pad; LCSC PN C17168
SW1: SSSS811101; LCSC PN C109335
SW2, SW3: TS-1187A-B-A-B; SW_SPST_TL3342_RT; LCSC PN C318884
TP1: VBUS; TestPoint_Pad_D1.0mm
TP3: RST; TestPoint_Pad_D1.0mm
TP4: GND CLIP; ronghe_RH-5016_C5199799; LCSC PN C5199799
TP5: 5V; TestPoint_Pad_D1.0mm
TP7: 3V3; TestPoint_Pad_D1.0mm
U1: RP2040; QFN-56_EP_7x7_Pitch0.4mm; LCSC PN C2040
U2: SRV05-4; SOT-23-6; LCSC PN C85364
U3: RT9080-33GJ5; SOT-23-5; LCSC PN C841192
U4: W25Q64JV; WSON-8-1EP_4x4mm_P0.8mm_EP2.2x3mm; LCSC PN C2940195
Y1: XYDBPCNANF-12MHZ; Crystal_SMD_3225-4Pin_3.2x2.5mm; LCSC PN C9002

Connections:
+5V: C16.1, Q2.3 (D), R21.2, TP5.1, U3.1 (VIN), U3.3 (EN); also elsewhere on the board
/RP2040 & USB/D+: R7.2, U1.47 (USB_D+)
/RP2040 & USB/D-: R6.2, U1.46 (USB_D-)
/RP2040 & USB/GPIO25_LED: R5.2, U1.37 (GPIO25)
/RP2040 & USB/PROG1: J2.1, R16.2
/RP2040 & USB/PROG2: J2.6, R17.2
/RP2040 & USB/QSPI_SCLK: U1.52 (QSPI_SCLK), U4.6 (SCK)
/RP2040 & USB/QSPI_SD0: U1.53 (QSPI_SD0), U4.5 (DI/IO0)
/RP2040 & USB/QSPI_SD1: U1.55 (QSPI_SD1), U4.2 (DO/IO1)
/RP2040 & USB/QSPI_SD2: U1.54 (QSPI_SD2), U4.3 (~WP/IO2)
/RP2040 & USB/QSPI_SD3: U1.51 (QSPI_SD3), U4.7 (~HOLD/IO3)
/RP2040 & USB/SWCLK: R16.3, U1.24 (SWCLK)
/RP2040 & USB/SWDIO: R17.3, U1.25 (SWDIO)
/RP2040 & USB/UART0_RX: J2.5, U1.3 (GPIO1)
/RP2040 & USB/UART0_TX: J2.3, U1.2 (GPIO0)
/RP2040 & USB/USBBOOT: R11.2, SW3.2
/RP2040 & USB/USB_D+: J1.A6 (D+), J1.B6 (D+), R7.1, U2.3 (IO2)
/RP2040 & USB/USB_D-: J1.A7 (D-), J1.B7 (D-), R6.1, U2.1 (IO1)
/RP2040 & USB/~QSPI_CS: R9.2, R11.1, U1.56 (~QSPI_CS), U4.1 (~CS)
/RP2040 & USB/~RESET: C5.1, R1.2, R4.2, R16.1, TP3.1, U1.26 (RUN)
GND: C1.2, C2.2, C3.2, C4.2, C5.2, C6.2, C7.2, C8.2, C9.2, C10.2, C11.2, C12.1, C13.1, C14.2, C15.2, C16.2, C17.2, C18.2, D1.1 (K), D3.1 (K), D4.1 (K), J1.A1 (GND), J1.A12 (GND), J1.B1 (GND), J1.B12 (GND), J1.S1 (SHIELD), J2.4, R2.2, R3.2, SW1.1 (A), SW1.2 (B), SW2.1, SW3.1, TP4.1, U1.19 (TESTEN), U1.57 (GND), U2.2 (VN), U3.2 (GND), U4.4 (GND), U4.9 (GND), Y1.2, Y1.4; also elsewhere on the board
GPIO2: U1.4 (GPIO2); also elsewhere on the board
GPIO3: U1.5 (GPIO3); also elsewhere on the board
GPIO4: U1.6 (GPIO4); also elsewhere on the board
GPIO5: U1.7 (GPIO5); also elsewhere on the board
GPIO6: U1.8 (GPIO6); also elsewhere on the board
GPIO7: U1.9 (GPIO7); also elsewhere on the board
GPIO8: U1.11 (GPIO8); also elsewhere on the board
GPIO9: U1.12 (GPIO9); also elsewhere on the board
GPIO10: U1.13 (GPIO10); also elsewhere on the board
GPIO11: U1.14 (GPIO11); also elsewhere on the board
GPIO12_PPS: U1.15 (GPIO12); also elsewhere on the board
GPIO13_WS2812_RGB_LED: U1.16 (GPIO13); also elsewhere on the board
GPIO14_BUTTON_0: U1.17 (GPIO14)
GPIO15_BUTTON_1: U1.18 (GPIO15)
GPIO18: U1.29 (GPIO18)
GPIO19: U1.30 (GPIO19)
GPIO20: U1.31 (GPIO20)
GPIO21: U1.32 (GPIO21)
GPIO22: U1.34 (GPIO22)
GPIO23: U1.35 (GPIO23)
GPIO24: U1.36 (GPIO24)
GPIO26_ADC0_LDR: U1.38 (GPIO26); also elsewhere on the board
GPIO27_ADC1: U1.39 (GPIO27); also elsewhere on the board
GPIO28_ADC2: U1.40 (GPIO28); also elsewhere on the board
GPIO29_ADC3: U1.41 (GPIO29)
I2C_SCL: R13.1, U1.28 (GPIO17); also elsewhere on the board
I2C_SDA: R14.1, U1.27 (GPIO16); also elsewhere on the board
unnamed: D1.2 (A), R5.1
unnamed: D2.2 (A), Q1.1 (G), Q2.1 (G), R8.1
unnamed: D2.1 (K), Q1.2 (S), Q2.2 (S), R10.1
unnamed: D3.2 (A), R21.1
unnamed: D4.2 (A), R15.1
unnamed: F1.2, J1.A4 (VBUS), J1.A9 (VBUS), J1.B4 (VBUS), J1.B9 (VBUS)
unnamed: J1.A5 (CC1), R2.1
unnamed: J1.B5 (CC2), R3.1
unnamed: R1.1, SW2.2
unnamed: C8.1, C10.1, C14.1, U1.23 (DVDD), U1.45 (VREG_VOUT), U1.50 (DVDD)
unnamed: C12.2, U1.20 (XIN), Y1.3
unnamed: C13.2, U1.21 (XOUT), Y1.1
PWR_OFF_SW_N: R8.2, R10.2, SW1.3 (C); also elsewhere on the board
VBUS: F1.1, Q1.3 (D), TP1.1, U2.5 (VP)

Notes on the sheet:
12MHz
5V 3A Max
3V3
8MB
*EX
Imax = 4A @ 25°C Vmin = 1.4V Vmax = 30V Rds_on = ~120mΩ
RP Protection w/ SW
27Ω IS SPEC, NOT JLC BASIC PART
Tooling Holes
ADC4 Connected to internal temp sense
ESD
Keep Flash & R close to RP240
USB
TAG CONN
Mounting
Large caps placed close to pin 44
FLASH
DEFAULT:
1u on pin 45
RP2040
600mA Max
USER LED
Fiducials
PROGRAMMING / DEBUG
SWD:

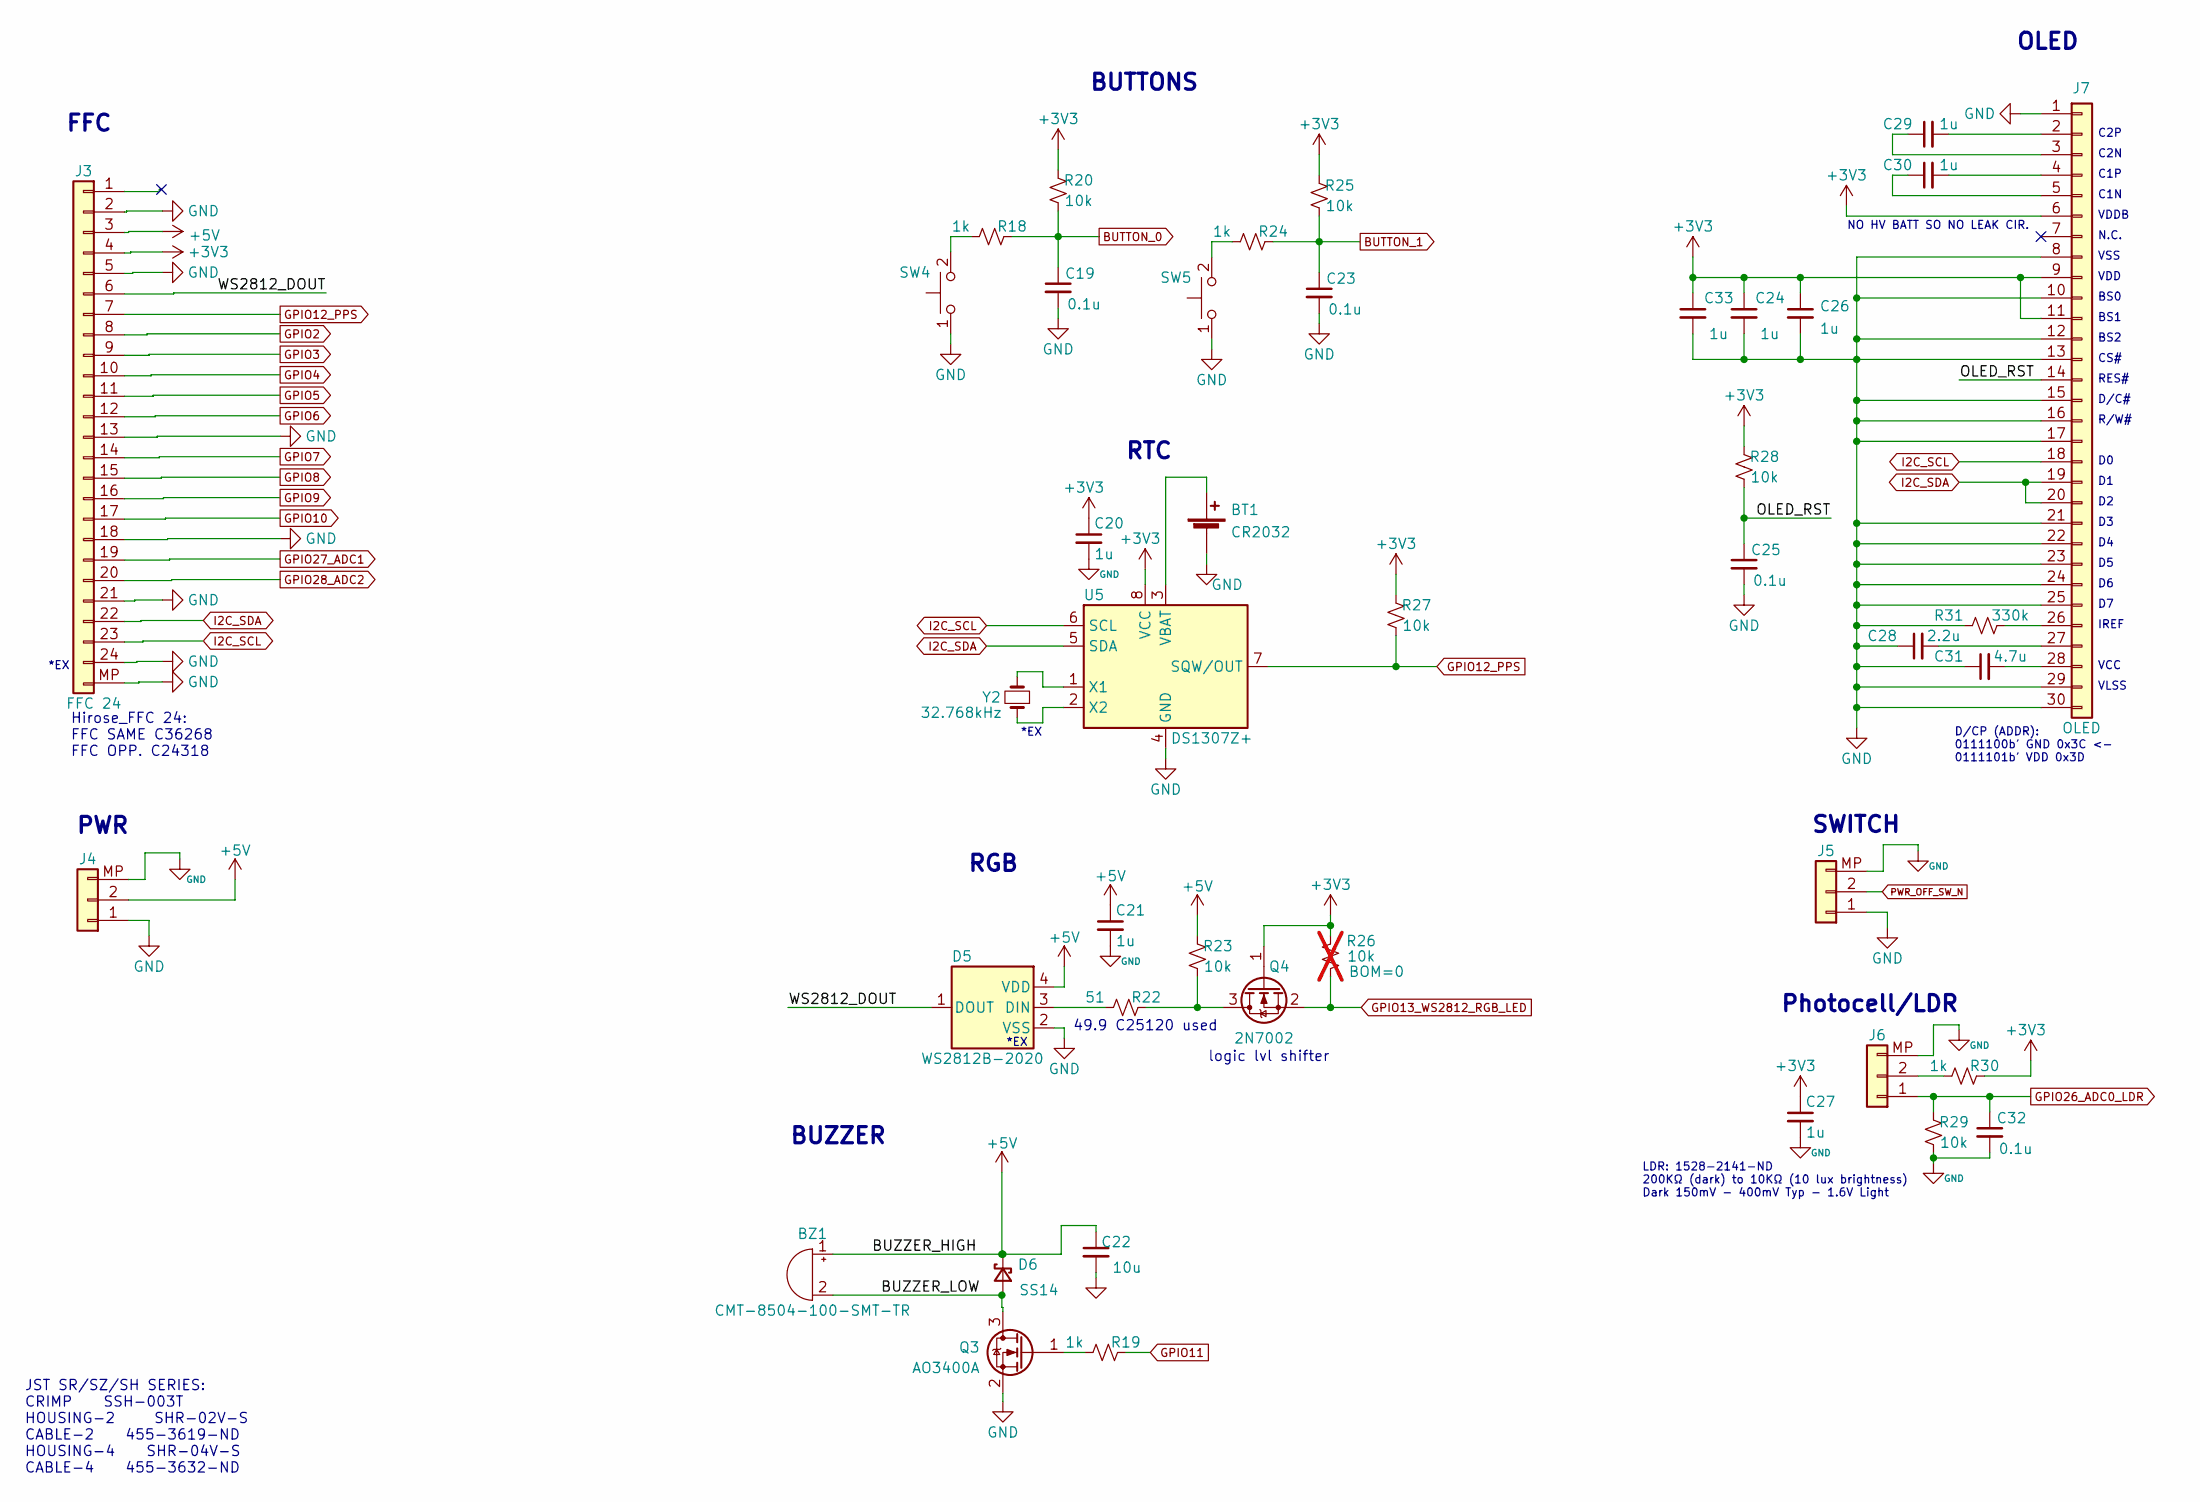
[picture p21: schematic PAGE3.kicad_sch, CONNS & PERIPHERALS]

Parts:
BT1: CR2032; Q&J_CR2032-BS-6-1; LCSC PN C70377
BZ1: CMT-8504-100-SMT-TR; MagneticBuzzer_CUI_CMT-8504-100-SMT; digi 102-CMT-8504-100-SMT-CT-ND
C19, C23, C25, C32: 0.1u; C_0402_1005Metric; LCSC PN C1525
C20, C21, C24, C26, C27, C29, C30, C33: 1u; C_0402_1005Metric; LCSC PN C52923
C22: 10u; C_0402_1005Metric; LCSC PN C15525
C28: 2.2u; C_0402_1005Metric; LCSC PN C12530
C31: 4.7u; C_0402_1005Metric; LCSC PN C23733
D5: WS2812B-2020; LCSC PN C965555
D6: SS14; D_SMA; LCSC PN C2480
J3: FFC 24; Hirose_FH12-24S-0.5SH_1x24-1MP_P0.50mm_Horizontal; LCSC PN C202112
J4, J5, J6: 5V; JST_SH_SM02B-SRSS-TB_1x02-1MP_P1.00mm_Horizontal; LCSC PN C160402
J7: OLED; OLED-128O064D_edit_reverse_v2; LCSC PN C2890596
Q3: AO3400A; SOT-23; LCSC PN C20917
Q4: 2N7002; SOT-23; LCSC PN C8545
R18, R19, R24, R30: 1k; R_0402_1005Metric; LCSC PN C11702
R20, R23, R25, R27, R28, R29: 10k; R_0402_1005Metric; LCSC PN C25744
R22: 51; R_0402_1005Metric; LCSC PN C25125
R26: 10k; R_0402_1005Metric; LCSC PN C25744; not fitted
R31: 330k; R_0402_1005Metric; LCSC PN C25778
SW4, SW5: TS-1187A-B-A-B; SW_SPST_TL3342_RT; LCSC PN C318884
U5: DS1307Z+; SOIC-8_3.9x4.9mm_P1.27mm; LCSC PN C8959
Y2: 32.768kHz; Crystal_SMD_3215-2Pin_3.2x1.5mm; LCSC PN C95361

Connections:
+5V: BZ1.1 (-), C21.1, C22.1, D5.4 (VDD), D6.1 (K), J3.3, J4.2, R23.1; also elsewhere on the board
/CONNS & PERIPHERALS/BUZZER_LOW: BZ1.2 (+), BZ1.3 (DUMMY1), BZ1.4 (DUMMY2), D6.2 (A), Q3.3 (D)
/CONNS & PERIPHERALS/OLED_RST: C25.1, J7.14, R28.2
/CONNS & PERIPHERALS/WS2812_DOUT: D5.1 (DOUT), J3.6
BUTTON_0: C19.1, R18.2, R20.2
BUTTON_1: C23.1, R24.2, R25.2
GND: BT1.2 (-), C19.2, C20.2, C21.2, C22.2, C23.2, C24.2, C25.2, C26.2, C27.2, C28.1, C31.1, C32.2, C33.2, D5.2 (VSS), J3.2, J3.5, J3.13, J3.18, J3.21, J3.24, J3.MP (MountingPoint), J4.1, J4.MP (Mounting_Point), J5.1, J5.MP (Mounting_Point), J6.MP (Mounting_Point), J7.1, J7.8, J7.10, J7.12, J7.13, J7.15, J7.16, J7.17, J7.21, J7.22, J7.23, J7.24, J7.25, J7.29, J7.30, Q3.2 (S), R29.2, R31.1, SW4.1, SW5.1, U5.4 (GND); also elsewhere on the board
GPIO2: J3.8; also elsewhere on the board
GPIO3: J3.9; also elsewhere on the board
GPIO4: J3.10; also elsewhere on the board
GPIO5: J3.11; also elsewhere on the board
GPIO6: J3.12; also elsewhere on the board
GPIO7: J3.14; also elsewhere on the board
GPIO8: J3.15; also elsewhere on the board
GPIO9: J3.16; also elsewhere on the board
GPIO10: J3.17; also elsewhere on the board
GPIO11: R19.2; also elsewhere on the board
GPIO12_PPS: J3.7, R27.2, U5.7 (SQW/OUT); also elsewhere on the board
GPIO13_WS2812_RGB_LED: Q4.2 (S), R26.2; also elsewhere on the board
GPIO26_ADC0_LDR: C32.1, J6.1, R29.1; also elsewhere on the board
GPIO27_ADC1: J3.19; also elsewhere on the board
GPIO28_ADC2: J3.20; also elsewhere on the board
I2C_SCL: J3.23, J7.18, U5.6 (SCL); also elsewhere on the board
I2C_SDA: J3.22, J7.19, J7.20, U5.5 (SDA); also elsewhere on the board
unnamed: BT1.1 (+), U5.3 (VBAT)
unnamed: D5.3 (DIN), R22.1
unnamed: J6.2, R30.1
unnamed: C29.2, J7.2
unnamed: C29.1, J7.3
unnamed: C30.2, J7.4
unnamed: C30.1, J7.5
unnamed: J7.26, R31.2
unnamed: C28.2, J7.27
unnamed: C31.2, J7.28
unnamed: Q3.1 (G), R19.1
unnamed: Q4.3 (D), R22.2, R23.2
unnamed: R18.1, SW4.2
unnamed: R24.1, SW5.2
unnamed: U5.1 (X1), Y2.2
unnamed: U5.2 (X2), Y2.1
PWR_OFF_SW_N: J5.2; also elsewhere on the board

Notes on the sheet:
VCC
BS2
PWR
OLED
*EX
SWITCH
BUZZER
RES#
R/W#
C1N
CS#
Photocell/LDR
NO HV BATT SO NO LEAK CIR.
logic lvl shifter
BS1
FFC
IREF
D/CP (ADDR): 0111100b' GND 0x3C <- 0111101b' VDD 0x3D
D/C#
49.9 C25120 used
VDDB
BS0
C2N
RTC
C1P
BUTTONS
LDR: 1528-2141-ND 200KΩ (dark) to 10KΩ (10 lux brightness) Dark 150mV - 400mV Typ - 1.6V Light
Hirose_FFC 24: FFC SAME C36268 FFC OPP. C24318
VLSS
VSS
C2P
JST SR/SZ/SH SERIES: CRIMP SSH-003T HOUSING-2 SHR-02V-S CABLE-2 455-3619-ND HOUSING-4 SHR-04V-S CABLE-4 455-3632-ND
N.C.
RGB
VDD

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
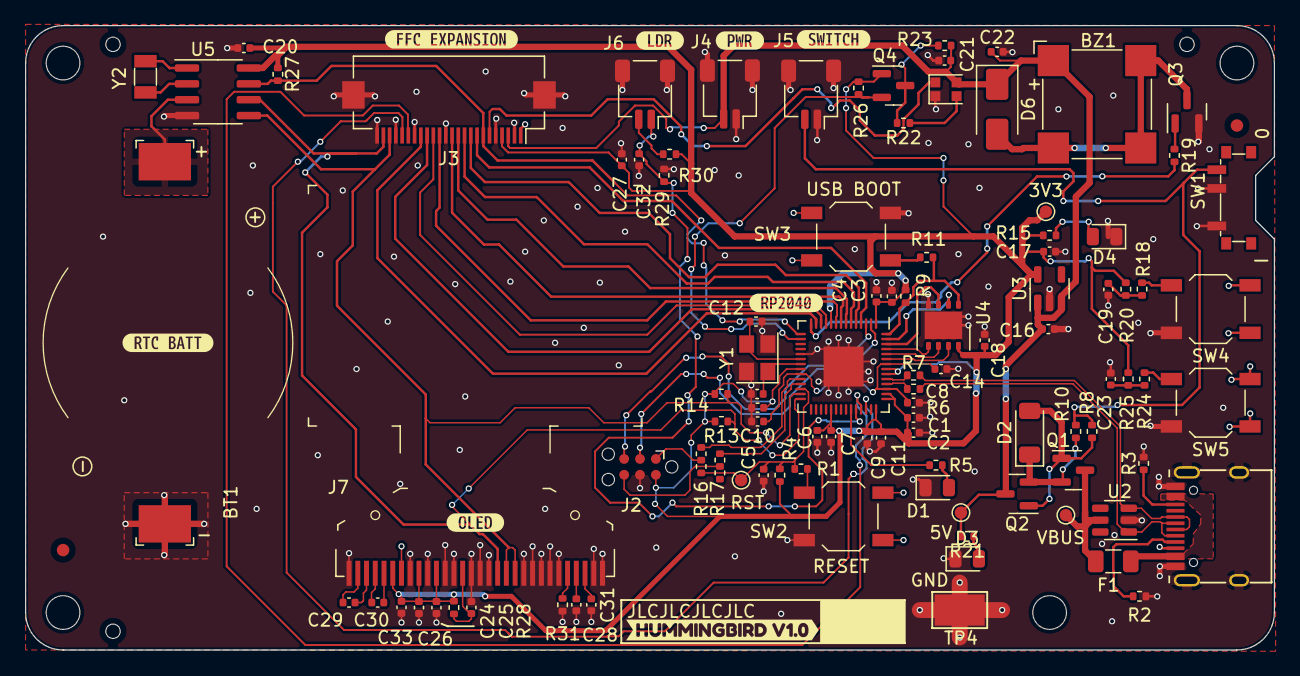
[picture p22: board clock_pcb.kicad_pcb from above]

Board: 2 copper layers, 100.0 x 50.0 mm, 117 parts (0 on the bottom side), 74 nets.

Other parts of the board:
kibuzzard-682261A9: G***; kibuzzard-682261A9
kibuzzard-682261BD: G***; kibuzzard-682261BD
kibuzzard-682261D0: G***; kibuzzard-682261D0
kibuzzard-682261E0: G***; kibuzzard-682261E0
kibuzzard-682261F1: G***; kibuzzard-682261F1
kibuzzard-68226165: G***; kibuzzard-68226165
kibuzzard-68226193: G***; kibuzzard-68226193
kibuzzard-68226263: G***; kibuzzard-68226263

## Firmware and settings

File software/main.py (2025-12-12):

"""***********************************************************
PROGRAM NAME:   main.py
PROGRAMMER:     M. STRIDE, 2025 11 28
DESCRIPTION:    Firmware for clock PCB.
TODO:           Note clock is free run updates not based on RTC SQWV
BUGS:           
***********************************************************"""
#---------------------------LIBS-----------------------------------
import machine
import utime
import time
import ssd1306 #save ssd1306 lib to pico first

from machine import ADC, Pin, Timer, PWM
from utime import sleep

#---------------------------SETUP-----------------------------------
#PINS
sensor_RP2040_die_temp = machine.ADC(4)
led = Pin(25, Pin.OUT)
ldr = ADC(Pin(26))
oled_rst = machine.Pin(15, machine.Pin.OUT)
button_SW4 = machine.Pin(1, machine.Pin.IN)
button_SW5 = machine.Pin(0, machine.Pin.IN) 
piezo = PWM(Pin(11))
piezo.duty_u16(0) 

#I2C
i2c0 = machine.I2C(0, sda=machine.Pin(16), scl=machine.Pin(17), freq=400000)
oled = ssd1306.SSD1306_I2C(width=128, height=64, i2c=i2c0, addr=0x3C)
DS1307_ADDR = 0x68

#GLOBAL VARS
adc_conversion_factor = 3.3 / (65535)
# debounce timers
last_sw4 = 0
last_sw5 = 0
DEBOUNCE_MS = 200   # ignore presses within 200 ms
RTC=False
MONTHS = ("Jan", "Feb", "Mar", "Apr", "May", "Jun",
    "Jul", "Aug", "Sep", "Oct", "Nov", "Dec")

#---------------------------FUNCTIONS-----------------------------------
def read_temp():
    data = sensor_RP2040_die_temp.read_u16() * adc_conversion_factor
    # Typically, Vbe = 0.706V @ 27°C, with a slope of -1.721mV (0.001721) per degree. 
    RP2040_die_temp = 27 - (data - 0.706)/0.001721
    return RP2040_die_temp

# --- Function: short beep ---
def beep(duration_ms=250, freq=2000, duty=500):    
    piezo.freq(freq)
    piezo.duty_u16(duty)
    utime.sleep_ms(duration_ms)
    piezo.duty_u16(0)
    
def oled_setup():
    oled_rst.low()
    utime.sleep(0.1)
    oled_rst.high()
    utime.sleep(0.1)

def oled_text_center(text, y):
    # Calculate start x to center text
    x = (128 - len(text) * 8) // 2
    oled.text(text, x, y)

def refresh_oled(t):
    #oled_pixel_check()
    oled.fill(0)   #clears screen
    oled_text_center("---Clock PCB---", 0)
    oled.text(f"RP2040 Die:{read_temp():.1f}C", 0, 9*1)
    volt, light_class = read_LDR()
    oled.text(f"LDR:{volt:.2f}V, {light_class}", 0, 9*2)
    if RTC:
        year, month, day, hour, minute, second, hour_12, ampm = read_time()
        month_str = MONTHS[month-1]           # Convert month number to 3-letter abbreviation
        oled_text_center(f"{year} {month_str} {day:02}", 9*3)
        oled_text_center(f"{hour_12:02}:{minute:02}:{second:02} {ampm}", 9*4)    #:02 pads leading zeros to ensure 2 dig
                # ---- Death clock bottom two lines ----
        d1, d2 = death_countdown(year, month, day, hour, minute, second)
        oled_text_center(d1, 9*5)   # Years and days
        oled_text_center(d2, 9*6)   # Hours, minutes, seconds
    else:
        oled.text(f"No RTC", 0, 30)
    oled.show()

# Timer callback toggles LED
def toggle_led(t):
    led.value(not led.value())

def oled_off():
    oled.fill(0)
    oled.show()
    oled_rst.low()

def read_LDR():
    raw = ldr.read_u16()                     # 0–65535
    voltage = (raw / 65535) * 3.3           # convert to voltage
      # Determine light class
    if voltage >= 2.8:
        light_class = "Flash"
    elif 2.5 <= voltage < 2.8:
        light_class = "Hi"
    elif 2.0 <= voltage < 2.5:
        light_class = "Light"
    elif 1.4 <= voltage < 2.0:
        light_class = "Dim"
    elif 0.1 <= voltage < 1.4:
        light_class = "Dark"
    else:
        light_class = "NoLDR"
    return voltage, light_class

def button_SW4_pressed(pin):   #ISR
    global last_sw4
    now = utime.ticks_ms()
    if utime.ticks_diff(now, last_sw4) > DEBOUNCE_MS:
        print("SW4 Pressed!")
        beep()  # quarter second beep, care function has wait and blocks, better to set a flah=g
        #one shot timer would also be better
        last_sw4 = now

def button_SW5_pressed(pin):   #ISR, no SW deboucing
    print("SW5 Pressed!")

#RTC Code
def bcd2dec(val):
    return (val // 16) * 10 + (val % 16)

def to_12h(hour):
    if hour == 0: return 12, "AM"
    if hour < 12: return hour, "AM"
    if hour == 12: return 12, "PM"
    return hour - 12, "PM"

def read_time():
    data = i2c0.readfrom_mem(DS1307_ADDR, 0x00, 7)
    second = bcd2dec(data[0] & 0x7F)
    minute = bcd2dec(data[1])
    hour   = bcd2dec(data[2])
    day    = bcd2dec(data[4])
    month  = bcd2dec(data[5])
    year   = bcd2dec(data[6]) + 2000

    hour_12, ampm = to_12h(hour)
    
    return (year, month, day, hour, minute, second, hour_12, ampm)

def RTC_FUNCTIONAL():
    global RTC
    if DS1307_ADDR in i2c0.scan():
        print("DS1307 RTC detected!")
        RTC=True
    else:
        print("DS1307 RTC not found!")
        RTC=False

def death_countdown(year, month, day, hour, minute, second):
    death_year, death_month, death_day = 2077, 3, 1

    now = utime.mktime((year, month, day, hour, minute, second, 0, 0))
    target = utime.mktime((death_year, death_month, death_day, 0, 0, 0, 0, 0))
    diff = target - now
    if diff < 0:
        return ("EXPIRED", "")

    total_days = diff // 86400
    years_left = total_days // 365
    days = total_days % 365
    hours = (diff % 86400) // 3600
    minutes = (diff % 3600) // 60
    seconds = diff % 60

    line1 = f"{years_left}y {days}d"
    line2 = f"{hours:02}h {minutes:02}m {seconds:02}s"
    return line1, line2

#---------------------------MAIN-----------------------------------
def main():
    utime.sleep(0.5)   #wait for serial terminal
    print("Clock PCB SW")
    RTC_FUNCTIONAL()

    # Create timer, period = 1000 ms (1 second)
    timer = Timer()
    timer.init(period=1000, mode=Timer.PERIODIC, callback=toggle_led)
    timer1 = Timer()
    timer1.init(period=500, mode=Timer.PERIODIC, callback=refresh_oled)
    # Setup IRQ buttons
    button_SW4.irq(trigger=machine.Pin.IRQ_FALLING,  handler=button_SW4_pressed)
    button_SW5.irq(trigger=machine.Pin.IRQ_FALLING,  handler=button_SW5_pressed)
    #ADD RGB,
    #Add up button plays buzzer and says on screen
    #down increments counter on screen

    
    utime.sleep(3) #run for X seconds
    beep()
    utime.sleep(0.250) 
    beep()
    piezo.duty_u16(0) 

    while True:
        if RTC:
            print(read_time())
        else:
            print("DS1307 RTC not found!")
        utime.sleep(10) 
    #Turn OFF everything but LED toggle
    #timer1.deinit()
    #oled_off()
    print("END")

if __name__ == "__main__":
    main()
#------------------------------------------------------------------

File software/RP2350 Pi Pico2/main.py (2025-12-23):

from machine import Pin, PWM
import time

# PWM on GPIO 1 and 2
pwm1 = PWM(Pin(1))
pwm2 = PWM(Pin(2))

# PWM on onboard LED (portable)
try:
    pwm_led = PWM(Pin("LED"))
except:
    pwm_led = PWM(Pin(25))

# Set PWM frequency (1 kHz is fine for LEDs)
pwm1.freq(1000)
pwm2.freq(1000)
pwm_led.freq(1000)

# 16-bit PWM range in MicroPython: 0–65535
MAX_DUTY = 65535

while True:
    for percent in range(0, 101, 10):
        duty = int((percent / 100) * MAX_DUTY)

        pwm1.duty_u16(duty)
        pwm2.duty_u16(duty)
        pwm_led.duty_u16(duty)

        print(f"Brightness: {percent}%  (duty={duty})")

        time.sleep(3)

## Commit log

2023-04-19 split from other deathclock repo
    [PAGE2.kicad_sch, PAGE3.kicad_sch, clock_pcb.kicad_pcb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]
2023-06-19 finished schematic parts, layout outline
    [2.kicad_sch, PAGE3.kicad_sch, clock_pcb.kicad_pcb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]
2023-06-21 changed all to single sided
    [PAGE2.kicad_sch, clock_pcb.kicad_pcb]
2023-06-22 layout work
    [PAGE2.kicad_sch, PAGE3.kicad_sch, clock_pcb.kicad_pcb]
2023-06-28 fusion360 assm is not nice
    [90690A035_Brass Hex Nut.STEP, 91635A180_Brass Washer.STEP, 93655A008_Male-Female Threaded Hex Standoff.STEP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]
2025-05-10 Routed, no gerbers
    [2.kicad_sch, 90690A035_Brass Hex Nut.STEP, 91635A180_Brass Washer.STEP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]
2025-05-12 Ordered pcba
    [PAGE2.kicad_sch, PAGE3.kicad_sch, bom.csv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]
2025-05-28 PCBA arrived, blinking
2025-12-09 firmware dev and hw fixes
    [01_Test_Unit.py, 02_Clock.py, LDR.py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]
2025-12-22 v2 org
    [2.kicad_sch, CONNS.kicad_sch, PAGE2.kicad_sch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]
2025-12-22 started v2
    [CONNS.kicad_sch, RP2040.kicad_sch, clock_module_v2.0.kicad_pcb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]
2025-12-23 schematic pick
    [CONNS.kicad_sch, RP2040.kicad_sch, clock_module_v2.0.kicad_pcb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]

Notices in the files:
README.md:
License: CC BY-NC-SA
